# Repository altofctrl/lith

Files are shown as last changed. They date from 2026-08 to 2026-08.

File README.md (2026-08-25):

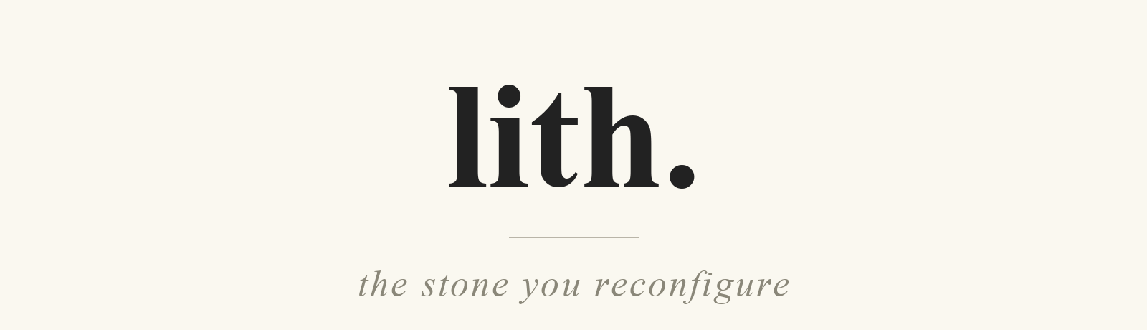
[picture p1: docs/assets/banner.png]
lith, the stone you reconfigure


<p align="center">
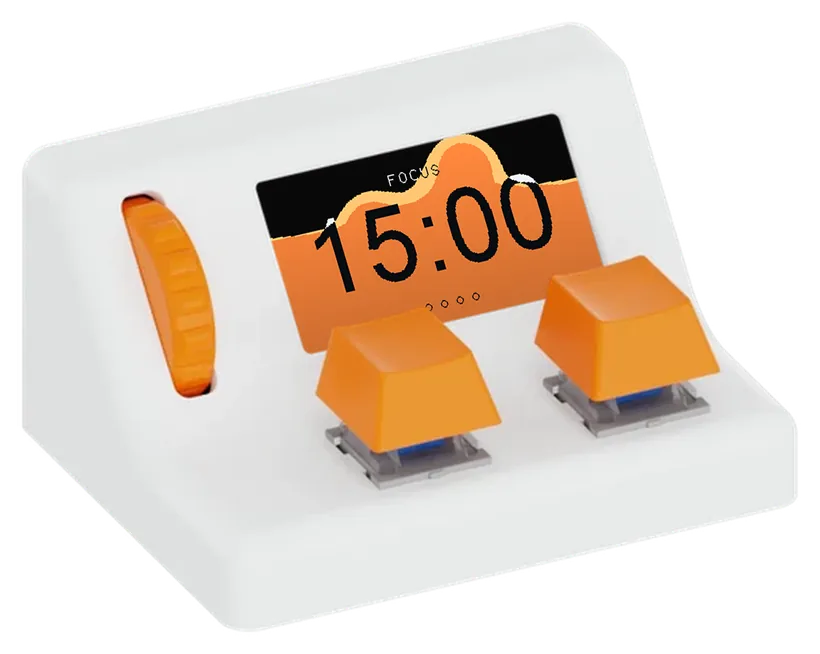
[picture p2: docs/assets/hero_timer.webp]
a lith running its pomodoro timer: a metaball fluid rising behind the countdown on the device's display
  
</p>

## the oldest tool we know how to make

1931, Olduvai Gorge, Tanzania.

In a ravein cut through the Serengeti plain, researchers discovered stones that had been deliberately broken, intentionally struck with larger ones till sharp flakes came away. They call this era of tool making **Oldowan** after the gorge, and it has examples dating back to 2.6 million years ago.

A stone chopper is the simplest
thing that is unmistakably *made*, and for most of the time there have been
hominins at all, it was the most complicated thing anyone could do. Making one
is harder than it looks: you have to read the stone, find a platform, and strike
at an angle that takes a flake off rather than shattering the core. People who
try it without being shown mostly fail.

These tools are some of the simplest things that can be unmistakably *made*, for most of the time we've been about it was the most complicated thing anyone could do.
However making one takes some skill, finding the right stone, striking the right angle with enough force to flake off instead of shatter.

_Knapping_ is difficult enough to learn, and
useless enough to invent from scratch, that it had to be **taught**. A 2015
experiment by Morgan and colleagues found that transmitting Oldowan technique
got measurably better as you moved from letting people watch, to gestural
teaching, to teaching with words.[1] Their argument is that toolmaking and
language leaned on each other as they grew. The first thing we made and the
first thing we said may have been the same conversation: *here, hold it like
this.*

## what lith is

lith is a small desk object: an ESP32-S3, a 320x170 display, a scroll wheel,
two key switches and a vibration motor in a printed shell. Out of the box it is
a pomodoro timer. That is the shape it arrives in, not the shape it has to keep.

The name is from *líthos*, stone. You reconfigure it by **knapping** it: you
describe what you want it to be, an agent called Oldowan writes the firmware,
and it is flashed to the device from the browser. The tools people make get
shared in the knappery.

The reason it is built this way is Bandura's: self-efficacy, the belief that
you can actually do the thing, is built most strongly from **mastery
experience**, and after that from watching someone like you succeed.[2] Which
role model, and for whom, turns out to matter: a systematic review by
Gladstone and Cimpian found that the effect depends on how *similar* the model
seems and how *attainable* their success looks, and that a model whose success
reads as out of reach can demotivate rather than encourage.[3] lith is
arranged so a beginner gets all three. You *watch* it be made through short form video content. You *make* one, by building it from its constituent parts. Then you *use* the
thing you made, on your desk, developing your own firmware by hand or with Oldowan's help.

[point on how overcoming the first hurdle towards that mastery experience improves continutity] 

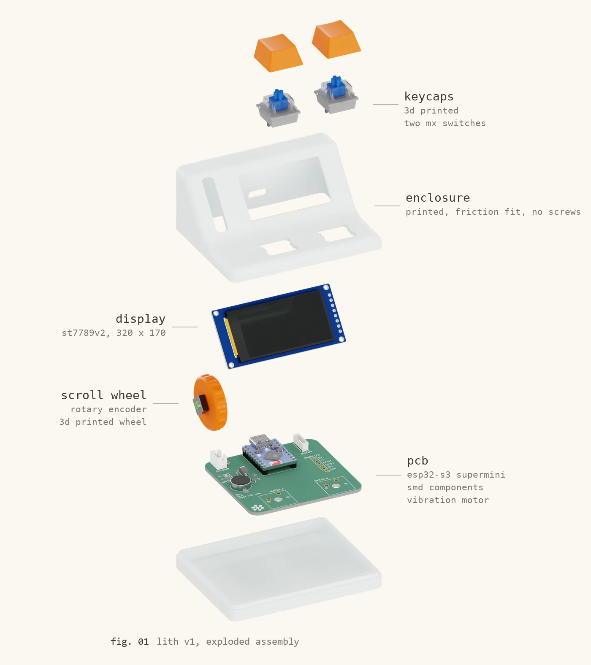
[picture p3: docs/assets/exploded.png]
lith v1, exploded assembly, with parts labelled


## what is in here

| | |
|---|---|
| [`firmware/`](firmware/) | The PlatformIO project that runs on the device. The pomodoro timer, the metaball fluid renderer, the display and input drivers. This is the stock shape lith ships in. |
| [`website/`](website/) | [lith.vidalion.co](https://lith.vidalion.co). The scroll-driven homepage, the onboarding walkthrough, the knapping bench and the knappery, every earlier version of them, and the Oldowan agent that writes firmware from a conversation. |
| [`research/`](research/) | Two studies run against the agent: whether the model tier behind Oldowan changes the quality of what it builds, and what the providers cost and how long they take. |

### website/

- `site/`: the four pages as they are served. `index.html` is the scroll-driven
  homepage, `onboarding.html` the walkthrough a new lith arrives with,
  `knapp.html` the knapping bench where you talk to Oldowan and flash the
  result from the browser, and `knappery.html` the shelf of builds other
  people have published.
- `agent/`: Oldowan. `oldowan.py` is the conversation and prompt layer,
  `builder.py` compiles and repairs the sketch it produces, `knappery.py` is the
  sharing side. `providers.json` selects the model; keys come from a
  `secrets.json` that is not in this repo.
- `versions/`: dated snapshots of every earlier version of the pages, back
  to before the renders existed.
- `assets/`: the WebP sequences the site actually serves.

### research/

- `ui-judge/`: 19 firmware builds from 11 models across 5 providers, compiled,
  rendered on the simulator and judged. The headline is that the **repair loop
  matters more than the model tier**: first-pass compile rate was 26%, and the
  builder's own repair passes took it to 79%.
- `provider-cost-latency/`: wall-clock latency and list price across the
  providers Oldowan can run on, replayed through one real 3-turn conversation.

Both are written up with their figures in
[`research/README.md`](research/README.md).

## references

1. Morgan, T. J. H., Uomini, N. T., Rendell, L. E., et al. (2015). Experimental
   evidence for the co-evolution of hominin tool-making teaching and language.
   *Nature Communications*, 6, 6029. https://doi.org/10.1038/ncomms7029

2. Bandura, A. (1997). *Self-Efficacy: The Exercise of Control*. W. H. Freeman.

3. Gladstone, J. R., & Cimpian, A. (2021). Which role models are effective for
   which students? A systematic review and four recommendations for maximizing
   the effectiveness of role models in STEM. *International Journal of STEM
   Education*, 8(1), 59. https://doi.org/10.1186/s40594-021-00315-x

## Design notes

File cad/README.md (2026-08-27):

# cad

Mechanical and PCB source for lith v1.

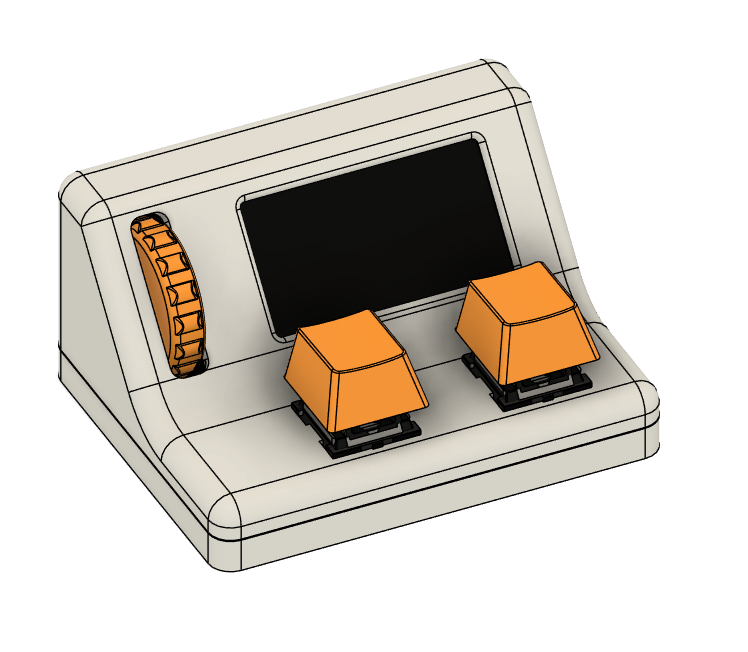
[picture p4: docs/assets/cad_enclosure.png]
lith v1 top shell: display cutout, two switches with keycaps, and the scroll wheel


    lith_assy_v1.step        full assembly, mechanical solids and PCB copper
    mechanical/
      lith_assy_v1.f3d       the Fusion source
      enclosure_top.stl      top shell, display cutout and switch plate
      enclosure_bottom.stl   base
      encoder_wheel.stl      scroll wheel
      keycap.stl             keycap, one per switch
    pcb/
      v1.0/                  KiCad project, first board
      v1.1/                  KiCad project, second board
        lith.kicad_sch       schematic
        lith.kicad_pcb       layout
        jlcpcb/gerber/       the fab output that was sent to JLC
        customs.pretty/      footprints drawn for this board

Each board folder is a self-contained KiCad project: it carries its own
`fp-lib-table` / `sym-lib-table` and the non-stock symbols, footprints and
connector 3D models the design pulls in, so it opens without the rest of the
library set.

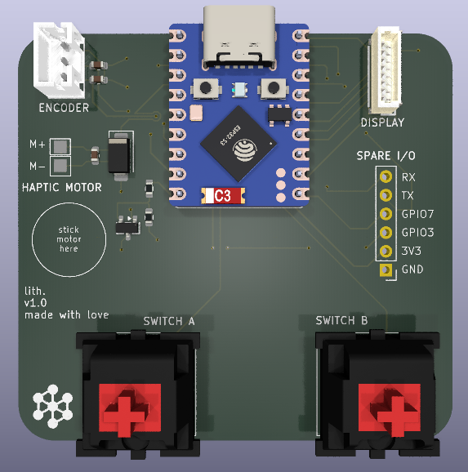
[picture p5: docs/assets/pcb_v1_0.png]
lith v1.0 board: the ESP32-S3-Zero module, encoder and display connectors, haptic motor pads, the spare I/O header and the two key switches


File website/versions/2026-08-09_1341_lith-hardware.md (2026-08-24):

# lith v1 · hardware reference

For anyone knapping their lith by hand in an IDE (Arduino IDE, PlatformIO, etc.)
instead of through Oldowan. This is the same ground truth Oldowan itself
builds from, paste it into your IDE's project notes, or straight into an AI
coding assistant if you're using one alongside your IDE.

## Board

- **ESP32-S3-Zero** (supermini form factor), 4MB flash QIO, native USB, CDC on boot
- Arduino core: `esp32` 3.x
- FQBN: `esp32:esp32:esp32s3:CDCOnBoot=cdc`
- Flash offsets: bootloader `0x0` · partitions `0x8000` · boot_app0 `0xe000` · app `0x10000`

## Pin map

| Signal | Pin |
|---|-----|
| TFT SCLK | 12  |
| TFT MOSI | 11  |
| TFT DC | 13  |
| TFT CS | 10  |
| TFT RST | 9 |
| TFT BLK | 8 |
| SW1 | 1 |
| SW2 | 2 |
| ENC_A | 4 |
| ENC_B | 5 |
| MOTOR | 6 |

## Display

ST7789V2, 170×320, driven with **LovyanGFX**. After `tft.setRotation(1)` it's
320×170 landscape. Reuse this init verbatim: the panel needs exact offsets
that aren't guessable from a datasheet:

```cpp
#define LGFX_USE_V1
#include <LovyanGFX.hpp>
class LGFX : public lgfx::LGFX_Device {
  lgfx::Panel_ST7789 _panel; lgfx::Bus_SPI _bus; lgfx::Light_PWM _light;
public:
  LGFX() {
    { auto cfg = _bus.config(); cfg.spi_host = SPI2_HOST; cfg.spi_mode = 0;
      cfg.freq_write = 50000000; cfg.freq_read = 16000000; cfg.spi_3wire = false;
      cfg.use_lock = true; cfg.dma_channel = SPI_DMA_CH_AUTO;
      cfg.pin_sclk = 12; cfg.pin_mosi = 11; cfg.pin_miso = -1; cfg.pin_dc = 13;
      _bus.config(cfg); _panel.setBus(&_bus); }
    { auto cfg = _panel.config(); cfg.pin_cs = 10; cfg.pin_rst = 9; cfg.pin_busy = -1;
      cfg.panel_width = 170; cfg.panel_height = 320; cfg.offset_x = 35; cfg.offset_y = 0;
      cfg.offset_rotation = 2; cfg.readable = false; cfg.invert = true;
      cfg.rgb_order = false; cfg.dlen_16bit = false; cfg.bus_shared = false;
      _panel.config(cfg); }
    { auto cfg = _light.config(); cfg.pin_bl = 8; cfg.invert = false;
      cfg.freq = 44100; cfg.pwm_channel = 7; _light.config(cfg); _panel.setLight(&_light); }
    setPanel(&_panel);
  }
};
// usage: LGFX tft; tft.init(); tft.setRotation(1); tft.setBrightness(180);
```

Draw into a 16-bit 320×170 `LGFX_Sprite` and `pushSprite()` it once per frame
rather than drawing primitives straight to the panel, avoids flicker/tearing.

## Switches

Two MX-style mechanical keyswitches, SW1 and SW2, wired **active low**. Use
`INPUT_PULLUP`. Debounce in software (~25 ms) and distinguish a short tap from
a long press (~800 ms hold); don't block waiting for either, compare against
`millis()` each loop pass.

## Encoder

The orange side scroll wheel: quadrature on ENC_A/ENC_B, `INPUT_PULLUP`, 4
quadrature steps per detent. **Keep this interrupt-driven, never polled in
`loop()`.** Attach a `CHANGE` interrupt on both pins into a small ISR that
only updates a `volatile` raw counter via a quadrature lookup table (no
Serial/heap/drawing inside the ISR). `loop()` reads that counter with
interrupts briefly disabled, divides by 4 to get detents, and only reacts to
the delta since the last detent; reacting per raw edge (4x too often, plus
contact bounce) makes scrolling feel jittery instead of matching the wheel's
physical click. This is also what decouples scroll responsiveness from
whatever else `loop()` is doing that tick (rendering, motor, etc.); the
single most common way a homebrew lith sketch ends up feeling laggy is
polling the encoder pins inside the render/update cadence instead of off an
interrupt.

## Vibration motor

Small motor behind an NPN low-side switch on the MOTOR pin. Drive with LEDC
PWM at 20 kHz, 8-bit resolution. Duty ~190 for a gentle buzz, 255 briefly for
a crisp tap. Treat it as fire-and-forget: set a `millis()`-based deadline and
let a small `motorService()` called every loop turn the PWM on/off
accordingly; never block waiting for a pulse to finish, and always let duty
fall back to 0 when idle.

## Libraries available on the build server

If you're compiling locally in an IDE you aren't limited to this list, but
anything you want to eventually publish through the knappery has to build on
these:

- LovyanGFX (display, reuse the init snippet above)
- QRCode by ricmoo (`qrcode.h`)
- Preferences (ESP32 NVS key-value storage)
- everything in the ESP32 Arduino core 3.x (WiFi, BLE, LEDC, etc.)

## Engineering heuristics

Distilled from the hardware bring-up sketch (`firmware/sketches/bringup.cpp`
in the [lith firmware repo](https://github.com/altofctrl/lith)). These are
what keep a lith sketch feeling responsive instead of laggy:

- Never call `delay()` in `loop()` or anywhere on the hot path. Every
  subsystem (buttons, motor, animation) should be driven off
  `millis()`-based timestamps so one slow feature can't stall input handling
  for the others.
- The encoder stays interrupt-driven, converted to detents before you act on
  it (see above); this is the single biggest lever on scroll feel.
- Debounce switches (~25 ms) and split short vs. long press (~800 ms)
  non-blocking.
- Throttle screen redraws to a fixed cadence (~25-40 fps) instead of drawing
  every loop iteration; draw into an off-screen sprite and push it once per
  frame.
- Motor/haptic output is fire-and-forget via a deadline timestamp, never a
  blocking wait.
- Drain all available Serial input each loop pass (`while (Serial.available())`),
  not one byte per pass.
- Use fixed-size `char` buffers with `snprintf` for logging/formatting, not
  the `String` class, to avoid heap fragmentation in a sketch that runs
  indefinitely.
- Keep `loop()` a short dispatch of small per-subsystem functions, each
  guarded by its own timing check, rather than inlining state machines
  directly in `loop()`.
- Net effect: any new feature must never come at the cost of encoder/button
  responsiveness. If something needs to block, block a state machine's
  transition, not the loop.
- There is no visible LED on the enclosure. Don't write status blinks,
  `digitalWrite` on the onboard LED pin, or any LED-based feedback into a
  sketch; the screen and motor are the only user-visible outputs.

## Stock firmware

The shipped firmware is a pomodoro timer: encoder sets the length shown when
idle; SW1 short press starts/pauses/resumes, SW1 long press resets the phase;
SW2 short press skips to the next phase, SW2 long press cycles which setting
the encoder edits; every fourth break is long. It also shows a QR splash to
`lith.vidalion.co/onboarding` for the first 10 boots after each new flash.
Full source: `firmware/src/main.cpp` in the
[lith firmware repo](https://github.com/altofctrl/lith).

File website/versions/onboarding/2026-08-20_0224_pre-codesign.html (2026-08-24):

← lith onboarding

onboarding

# 01 | welcomewell done.

Step one was "scan the code on the screen." Seeing as you're reading this, you did it.

This page is the manual. It's short, because the interesting part isn't what it does now. It's what you'll make it do later.

keystwo mx switches

enclosureprinted, pinch fit, no screws

displayst7789v2, 320 x 170

scroll wheelrotary encoder, orange

esp32-s3 superminithe brain, plus a haptic buzz

fig. 01 your lith, exploded · every part, in the order it goes together.

scroll ↓

## 02 | out of the boxit's a pomodoro timer.

Right now your lith runs its founding firmware: a focus timer built on the pomodoro method. Twenty-five minutes of work, five of rest.

- Turn the wheel to set the length, then tap the first key to start. Tap it again to pause, hold it to reset the phase.
  lith from the left. The wheel turns, the time climbs from 25 to 40 minutes, the first key goes down, and the screen fills as the timer starts
- The screen counts down. Nothing to press until it ends.
  lith head on. The number falls from 25:00 to 00:00 and the liquid on the screen drains with it
- When a block ends, lith buzzes and rolls into a 5 minute break. Tap the second key to skip ahead; hold it to choose which setting the wheel edits.
  lith with both keys facing you. The block runs out, the device buzzes, the screen turns green for a break; the second key is tapped and the break is skipped, then held down until the screen switches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
- Every fourth break is a long one.
  lith from a high angle. The fourth focus block runs out and the screen turns green for a long break, all four dots now filled

by the way: the QR splash you scanned retires itself after the first ten boots.

## 03 | one stone, many toolsthe timer is just the first shape.

lith is a reconfigurable computer. The pomodoro firmware is one arrangement of it, the way a hand axe is one use of a flint. You can reshape yours: a macropad, a bus countdown, a word of the day display or knap it right back to the default pomodoro whenever you want.

knap /nap/ · verb · to shape a stone tool by striking flakes from it. Here: to shape your lith into a new tool by describing the tool you want.

## 04 | knapp your owntwo ways to shape it.

However you'd rather work: talk to an agent, or open an IDE and wire it up yourself. Both start from the same hardware.

agent

### chat with oldowan

Oldowan is the agent you knapp with, named after the oldest known stone toolkit. Tell it what you want your lith to become, answer a few multiple-choice questions, and it writes the firmware and walks you through flashing it. No code required, though you can read every line it writes.

open the knapping bench →

or

diy

### wire it up yourself

Prefer Arduino IDE (https://www.arduino.cc/en/software), PlatformIO (https://marketplace.visualstudio.com/items?itemName=platformio.platformio-ide), or your own coding agent at the wheel? Here's the hardware ground truth: pin map, display init snippet, and the timing rules that keep the encoder feeling immediate instead of laggy.

- pin map + display init
- libraries the build server has
- engineering heuristics from bring-up

download hardware.md →

you

I want my lith to remind me to water the plants.

oldowan

Good use of a stone. How should it remind you?

a a plant sprite that wilts on screen until you press the button

b a gentle chime every morning at a set time

c only when the soil sensor I'll wire up says so

… or type your own answer

you'll need a laptop for the flashing part. Knapping flashes new firmware onto your lith over USB, straight from the browser using Web Serial. That works in Chrome or Edge on a laptop or desktop. It does not work from phones, and not in Firefox or Safari, which don't support Web Serial. You can start chatting and shaping from the phone you're holding, then open the same link on a laptop to flash; your conversation travels with it.

## 05 | the knapperytools are for sharing.

Every knapp can be published to the community, where anybody can flash it, star it, and discuss it under the listing, like a forum stitched to a toolbank. Always read the source before you flash something a stranger knapped. A report button is on every listing, and a small model skims each published sketch and quietly flags anything that looks off for a human to check. Treat that as a backstop, not a guarantee: nothing is blocked automatically, and it is no substitute for reading the code yourself.

open the knappery →

## 06 | that's itgo focus.

Press the button on your lith and get 25 minutes of something done. If you wish it did something else, knapp it.

back to lith.vidalion.co →

lith.vidalion.co/onboarding · a vidalion (https://vidalion.co) joint · mmxxvi

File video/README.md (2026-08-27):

# Mastery Modeling

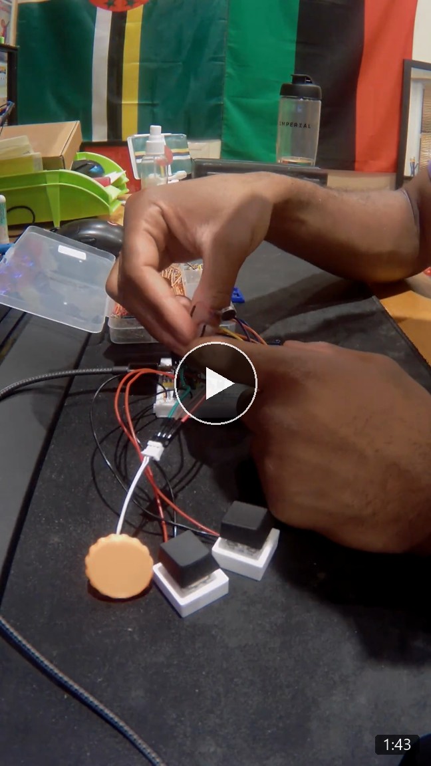
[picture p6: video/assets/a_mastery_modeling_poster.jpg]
Mastery Modeling
[](a_mastery_modeling.mp4)

# Coping Modeling

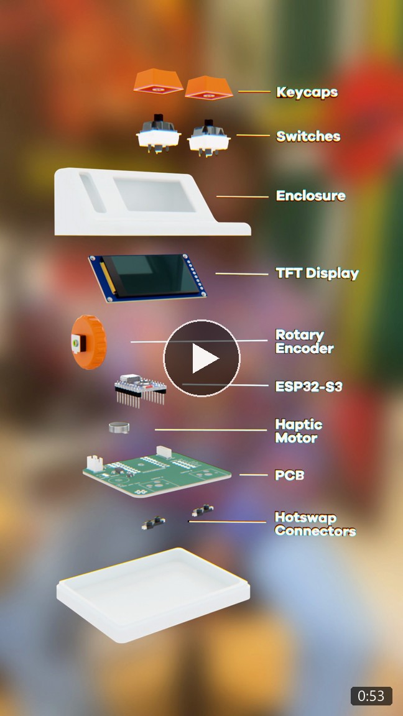
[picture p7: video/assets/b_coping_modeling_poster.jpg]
Coping Modeling
[](b_coping_modeling.mp4)

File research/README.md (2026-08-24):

# research

Two studies, both aimed at the same question from different sides: **can a
language model be trusted to write the firmware a beginner asked for?** One
looks at the quality of what comes out, the other at what it costs to get it.

Both run against Oldowan, the co-design agent in [`../website/agent/`](../website/agent/).

---

## ui-judge

19 firmware builds, generated from one brief by 11 models across 5 providers,
compiled, rendered on a simulator that runs the sketches as the device would,
and then judged.

### the repair loop matters more than the model

This is the finding that changed how the agent is built. Straight out of the
model, only 5 of 19 builds compiled. After `builder.py`'s repair passes, 15 of
19 did.

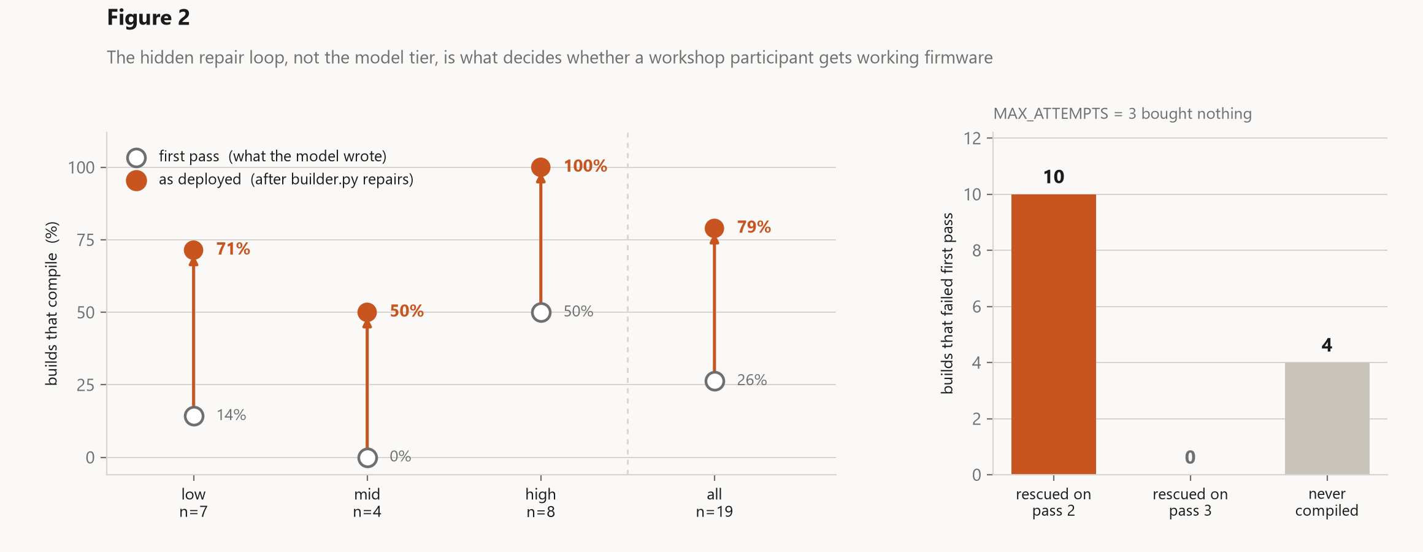
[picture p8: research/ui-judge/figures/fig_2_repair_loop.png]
First-pass versus as-deployed compile rate, and which pass rescued each build


Every rescued build was fixed on **pass 2**. `MAX_ATTEMPTS = 3` bought nothing
on this brief, which means the third attempt is cost with no return.

### tier buys hierarchy, not coverage

Every build that compiles distinguishes more or less all six states of the
journey, so journey coverage does not separate the tiers at all (p = 0.87).
What separates them is whether the screen is laid out well.

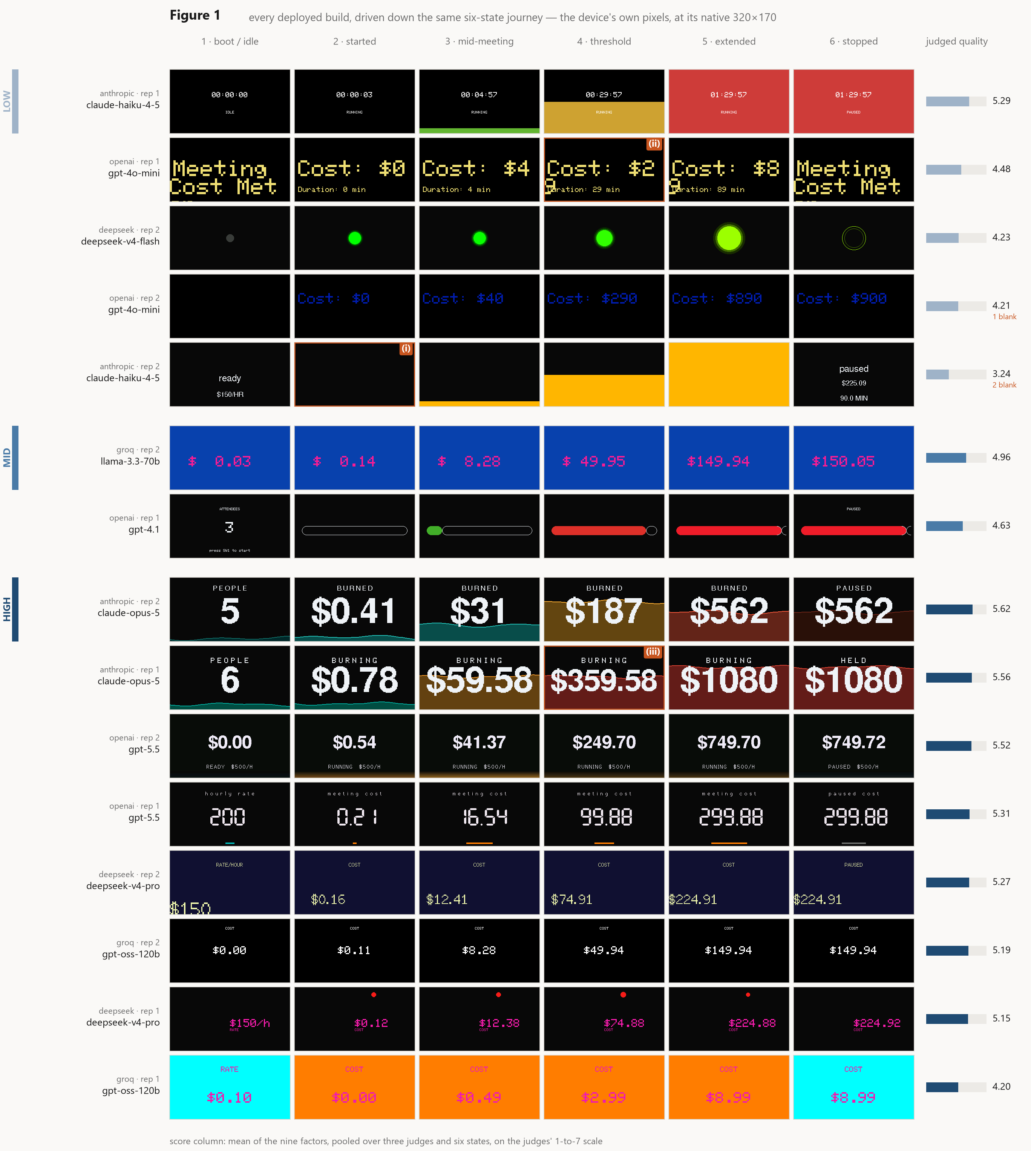
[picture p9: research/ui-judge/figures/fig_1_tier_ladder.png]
15 builds by 6 journey states, sorted by judged quality within tier


That matrix is 2735 x 3052 px, which is right for reading on screen and useless
once a word processor scales it into a column. The same journey, one
representative build per tier, sized for a 16 cm text column:

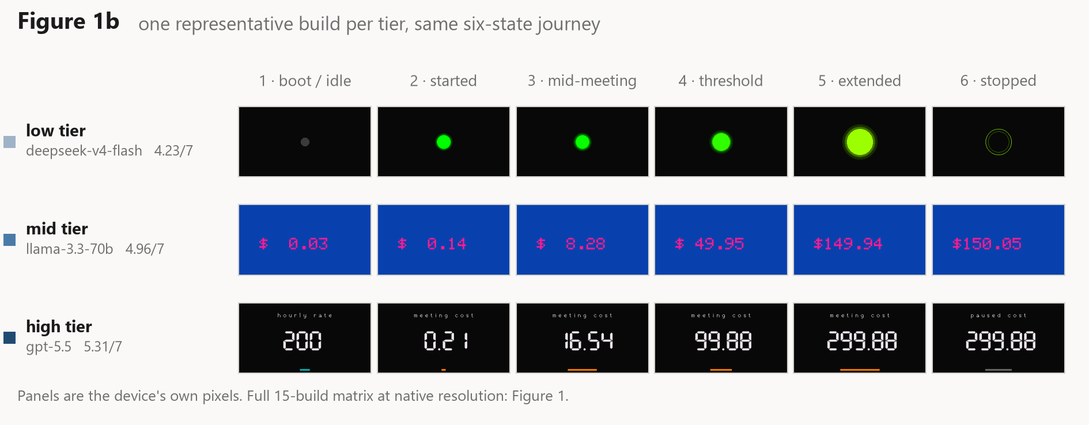
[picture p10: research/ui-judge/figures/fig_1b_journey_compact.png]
One representative build per tier across the six-state journey


The three rows are the argument in miniature. All three compile, all three
cover the journey, and all three are honestly reporting the same running cost.
The low-tier build says it with a green dot that gets bigger. The mid-tier
build says it with a bare number. Only the high-tier build tells you what the
number *is*, puts the label above it, and gives the state its own indicator.

On the pairwise task the higher tier wins 0.90 of the time. But rep-to-rep
variance beats the tier effect: two `claude-haiku-4-5` runs of the same prompt
differ by 2.05 on the nine-factor mean, where the whole low-to-high tier gap is
0.94.

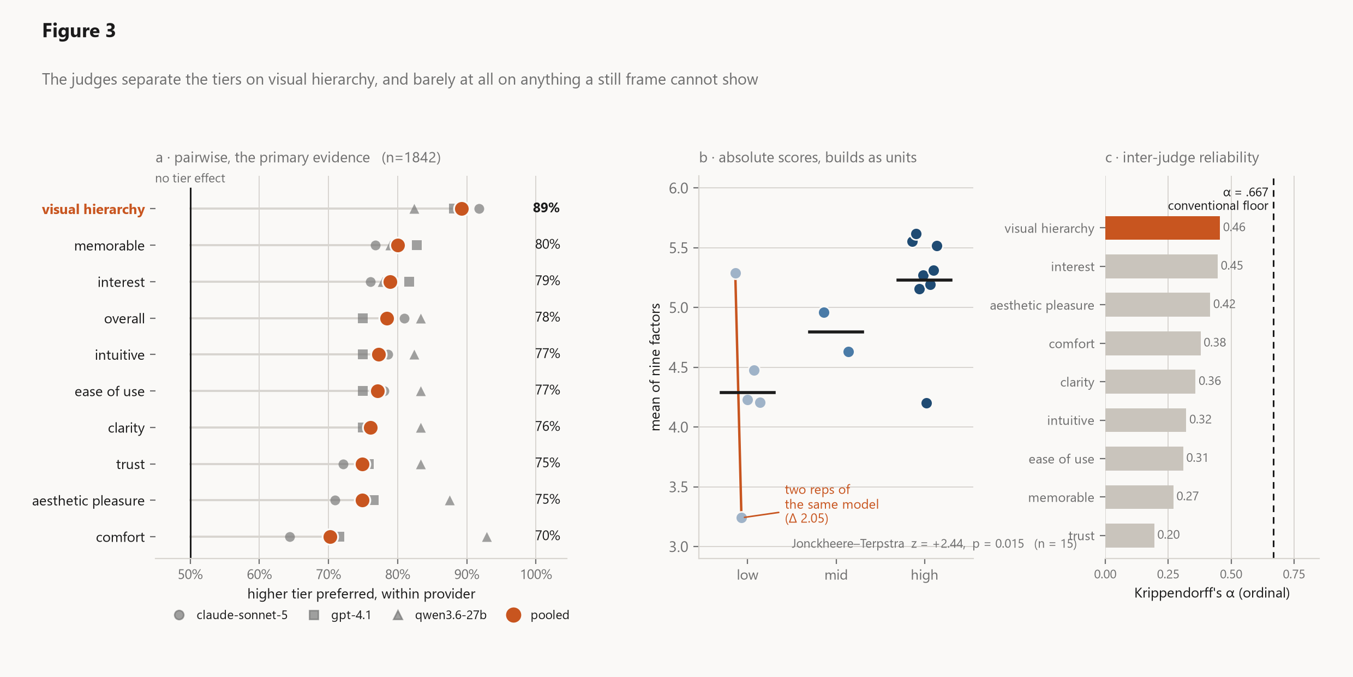
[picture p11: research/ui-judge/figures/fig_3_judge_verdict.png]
Pairwise win rate by factor, per-build scores by tier, and inter-judge agreement


Inter-judge agreement is weak (Krippendorff's alpha 0.35), so the absolute
Likert scores are descriptive only. The pairwise comparison is what carries the
argument.

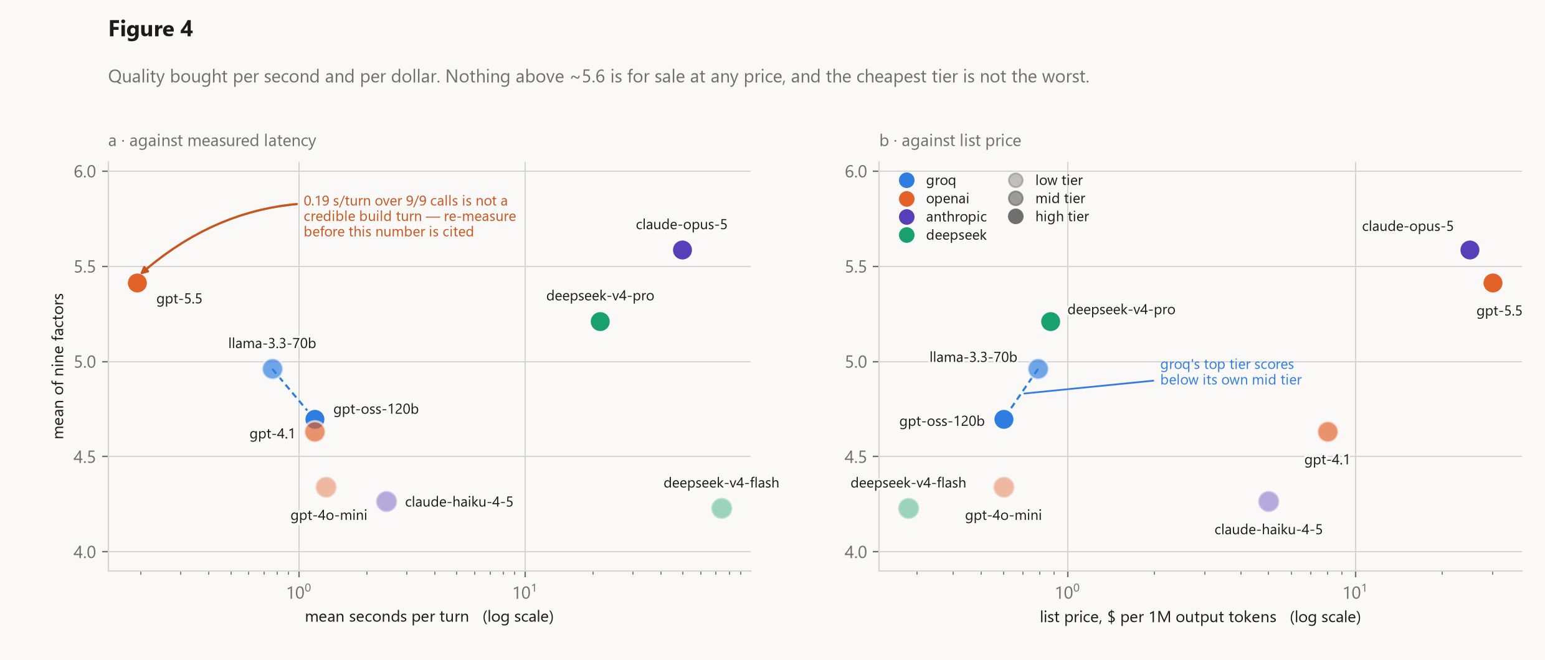
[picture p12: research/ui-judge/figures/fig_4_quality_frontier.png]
Nine-factor mean against measured latency and against list price


### where the instrument comes from

The nine factors are not invented here. They are taken from Luera et al.,
*MLLM as a UI Judge* (arXiv:2510.08783), an Adobe Research benchmark that
validates multimodal LLMs as predictors of human perception of interfaces:
ease of use, clarity, visual hierarchy, memorability, trust, intuitiveness,
aesthetic pleasure, interest and comfort, checked against 9,296 human Likert
responses over thirty interfaces with GPT-4o, Claude 3.5 Sonnet and
Llama-3.2-11B-Vision as the judges. Their Table 1 gives the battery, their
Figure 7 gives the prompt, and their Task 2 is the pairwise comparison used
here.

Their results are the reason this study is shaped the way it is. Their judges
land within one Likert point of the human mean 72 to 77% of the time, but get
the *exact* score right only 35 to 38% of the time. So absolute scores are
soft and comparisons are firm, and the design follows: score everything, but
argue from the pairwise task.

That paper is itself the UI-specific descendant of a now-standard method.
LLM-as-a-judge was established by Zheng et al., *Judging LLM-as-a-Judge with
MT-Bench and Chatbot Arena* (NeurIPS 2023 Datasets and Benchmarks,
arXiv:2306.05685), which showed a strong model scoring open-ended text could
reach roughly the 80% agreement with human preference that humans reach with
each other, and which named the failure modes that come with it: position
bias, verbosity bias, and self-enhancement bias, the tendency of a judge to
prefer its own output.

Those three biases are why this run is built the way it is. Every pairwise
comparison is shown in **both A/B orderings**, so a judge that flips when the
options are swapped is recorded as having no preference rather than being
silently resolved in whichever direction it happened to be asked. The judges
are drawn from **three different model families** (`claude-sonnet-5`,
`gpt-4.1`, `qwen3.6-27b`) precisely so that self-enhancement cannot quietly
decide the ranking, since a judge scoring builds from its own family is the
obvious hazard when the thing being judged is model output. And each frame is
scored three times with the median taken, to damp sampling noise.

**One honest correction to how this study describes its own source.** The
protocol justified treating pairwise as primary by citing Luera et al.'s
"roughly 90%" pairwise agreement. That figure applies only to the subset of
comparisons where two interfaces were separated by a large human score gap.
Their *overall* pairwise accuracy against human preference is 52.96 to 59.98%
(Claude 59.98%, GPT-4o 59.60%). The design choice still stands, and this run's
own alpha of 0.35 independently says the absolute scores cannot carry the
argument. But the pairwise result here should be read against a 53 to 60%
baseline, not against 90%.

**The chain of borrowed validation gets thinner at every link.** Zheng et al.
validated judges on text. Luera et al. carried the method across the modality
gap to rendered, full-size, professionally designed web screens. This study
carries it one gap further, onto a 320x170 embedded panel showing six frames
of a timer. No human ratings of *these* screens were collected. What is
established here is how MLLM judges rank the output of different provider
tiers. That lith's actual users would rank them the same way is assumed, not
shown.

### where to look

| | |
|---|---|
| [`RESULTS.md`](ui-judge/RESULTS.md) | The full write-up of the run. |
| [`SECTION_codesign_agent.md`](ui-judge/SECTION_codesign_agent.md) | The ~1,800-word report section this became. |
| [`DEVIATIONS.md`](ui-judge/DEVIATIONS.md) | Where the run departed from the written protocol. |
| [`results/`](ui-judge/results/) | Every CSV and raw judge response. |
| [`code/`, `code_deployed/`](ui-judge/code/) | The sketches as generated, and as they ended up after repair. |
| [`harness/`](ui-judge/harness/) | The gates, the judges, the simulator and `make_figures.py`. |

Run 2026-08-16; written up 2026-08-20.

---

## provider-cost-latency

Wall-clock latency and list price across every provider Oldowan can be pointed
at, replayed through one real 3-turn conversation taken verbatim from a session
rather than a synthetic prompt.

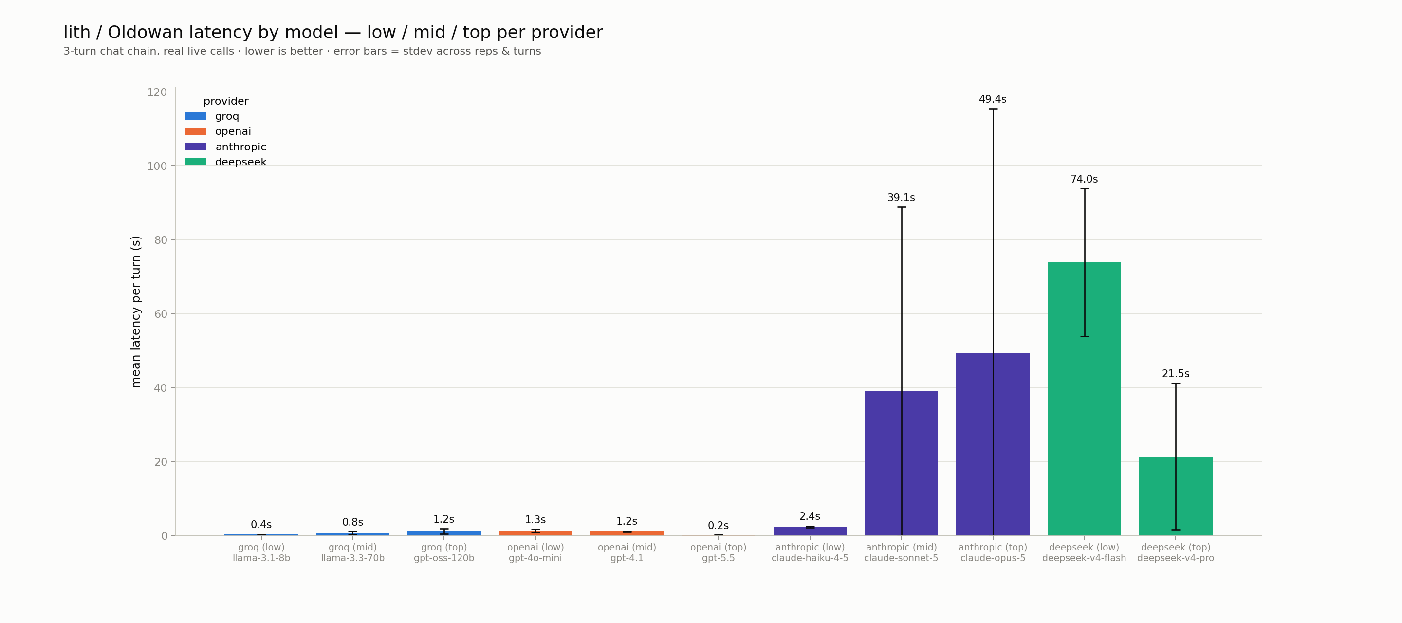
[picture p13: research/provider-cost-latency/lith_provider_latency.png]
Mean latency per turn by model, grouped by provider


Groq is the latency floor by a wide margin, which is the inference hardware
rather than a small-model effect. The reasoning-heavier models are both slower
and far noisier, and for an agent that streams its answer to someone waiting,
the spread matters as much as the mean.

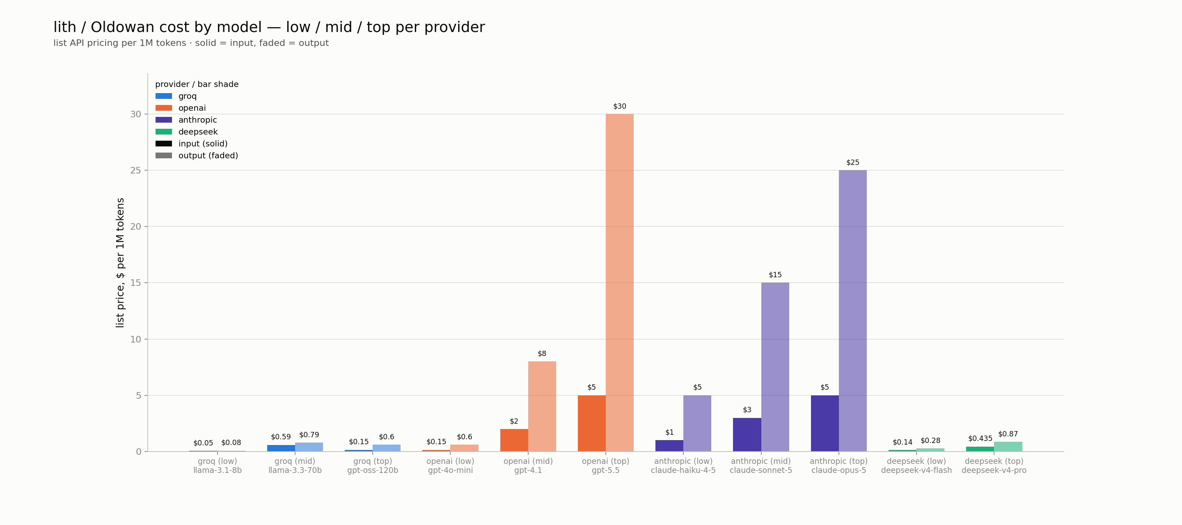
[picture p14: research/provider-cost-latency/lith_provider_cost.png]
Input and output list price across the 11-model matrix


Run 2026-08-10.

### read the spreadsheet, not the prose

Three things anyone using this data needs to know first:

- **`lith_provider_latency.md` is stale against `lith_provider_latency.xlsx`.**
  The prose describes an 8-model run; the sheet, saved 37 minutes later, is an
  11-model run that disagrees hard (sonnet-5 at 39.087 s mean, not 1.78 s
  stdev). Trust the sheet.
- `bench_build.py` and `bench_latency.py` hand `oldowan._call_anthropic`'s
  return value straight to `parse_envelope`, but the anthropic path returns a
  dict where the openai path returns a bare string. The anthropic rows in the
  older CSVs are wrong because of it.
- The `gpt-5.5` figure (0.193 s mean, 0.012 s stdev) is not plausible and needs
  re-measuring before it is cited anywhere.

One more trap for anyone re-running a tier sweep: `providers.json` sets
`effort: medium`, and `claude-haiku-4-5` returns a 400 on that field. It has to
be dropped for that model specifically.

---

## what this suggests for lith

Six things follow from the two studies. They are ordered by how much they
would change if acted on.

**1. Spend on the repair loop, not on the model.** This is the largest
effect in either study by a wide margin: 26% of builds compiled on the first
pass, 79% after repair. No tier upgrade available anywhere in the price table
buys a jump of that size. If there is engineering time to spend on the agent,
it goes into `builder.py`, not into `providers.json`.

**2. Set `MAX_ATTEMPTS = 2`.** Every build that repair rescued was fixed on
pass 2. The third attempt rescued nothing on this brief while costing a full
generation round-trip on the slowest path a user can be on. Keep the third
pass only if a later brief shows it earning its place.

**3. Sample rather than upgrade.** Two runs of the same prompt on
`claude-haiku-4-5` differ by 2.05 on the nine-factor mean; the entire
low-to-high tier gap is 0.94. Variance is more than twice the signal. That
makes best-of-k on a cheap fast model a better use of the same money than one
attempt on an expensive one, and the pairwise judge is already the instrument
for picking the winner.

**4. Put hierarchy in the prompt, since that is what tier is actually
buying.** Journey coverage does not separate tiers at all (p = 0.87).
Everything that compiles shows all six states. What separates them is visual
hierarchy, and Figure 1b shows what that means concretely: one dominant
value, a label that says what the value is, and a state indicator that is not
the value itself. Those are writable rules. Encoding them in
`device_profile.json` would hand the low tier most of what the high tier is
being paid for.

**5. Treat latency as a design property, not an implementation detail.**
Groq returns in well under half a second; `claude-sonnet-5` averages 39
seconds with a 49-second standard deviation. Somebody knapping their first
lith is watching a spinner for that whole time, on the exact afternoon the
project is trying to convert into a mastery experience. A fast model for the
first build with a strong model held back for refinement fits both the
self-efficacy argument and the cost table.

**6. Buy the human validation before the claim is load-bearing.** The
instrument's alignment with human judgement is inherited from a paper about
full-size web screens. Thirty people rating a subset of these frames would
convert the weakest part of the argument into the strongest, and it is a
morning's work. Until then, phrase findings as "MLLM judges prefer" rather
than "users prefer".

One caution that cuts against acting too hard on any of this: all 19 builds
answer a single brief, the mid tier is unbalanced and missing
`claude-sonnet-5` entirely, and six still frames discard motion, which is a
large part of what a glanceable display actually does. The repair-loop finding
is robust because it is enormous. The tier findings are directional.

---

## references

1. Luera, R., et al. (2025). MLLM as a UI Judge: Benchmarking Multimodal LLMs
   for Predicting Human Perception of User Interfaces. arXiv:2510.08783.
   https://arxiv.org/abs/2510.08783

2. Zheng, L., Chiang, W.-L., Sheng, Y., et al. (2023). Judging LLM-as-a-Judge
   with MT-Bench and Chatbot Arena. *Advances in Neural Information Processing
   Systems 36, Datasets and Benchmarks Track*. arXiv:2306.05685.
   https://arxiv.org/abs/2306.05685

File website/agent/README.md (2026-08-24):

# lith knapp backend

Oldowan chat + firmware compile + flash artifacts for lith.vidalion.co/knapp.
Flask on 127.0.0.1:3130, proxied by nginx at `lith.vidalion.co/api/`.

## Run

- Autostarts on boot via `@reboot` cron in aaron's crontab, in a screen
  session named `lith-knapp` (same pattern as backstage).
- Manually: `screen -dmS lith-knapp /home/aaron/lith-backend/run.sh`
- Health: `curl http://127.0.0.1:3130/api/health`

## Pieces

- `app.py`: Flask API (session, chat, build status, binaries, replay).
- `oldowan.py`: agent orchestration. JSON envelope protocol
  (say / ask / build / done), provider adapters, mock provider.
- `knappery.py`: community listings (SQLite `knappery.db`). No accounts;
  edit_token gates delete, voter_id dedups stars. Moderation is by hand via
  `admin.py`; nothing is hidden automatically.
- `builder.py`: single-worker compile queue using arduino-cli
  (`~/.local/bin/arduino-cli`, esp32 core 3.3.11, FQBN in
  `device_profile.json`). Hidden repair loop: compile errors go back to
  the agent as `[internal]` messages, up to 3 passes, invisible to the user.
- `providers.json`: the provider framework. `active` selects one. Formats:
  `anthropic` | `openai` (covers Groq/Mistral/DeepSeek/Ollama/vLLM/...) |
  `mock` (scripted, no key, for testing the full flow).
- `secrets.json` (not committed anywhere): `{"ANTHROPIC_API_KEY": "..."}`,
  referenced from providers.json as `${VARS}`. Env vars also work.
- `device_profile.json`: hardware ground truth injected into the system
  prompt; pin map is TODO until confirmed. Also carries FQBN and flash
  offsets for the esp-web-tools manifest.
- `sessions/`, `builds/`: runtime state, one JSON per session, one dir per
  build (sketch, out/ binaries, manifest.json, meta.json).

## Going live with a real provider

1. Put a key in `secrets.json` (chmod 600).
2. Set `"active"` in providers.json to `anthropic` (or another entry).
3. Restart: `screen -S lith-knapp -X quit; screen -dmS lith-knapp ./run.sh`

## Automated review (advisory)

Two small-model checks run on the provider's `guard_model`, both forced
single tool calls returning a JSON bool, and both fail open so a flaky API
call never blocks a user:

- `oldowan.is_adversarial()` screens chat input for jailbreak attempts
  before it reaches Oldowan's system prompt. Hits go to
  `adversarial_log.txt`. Two rules keep a false positive cheap: messages
  matching an option Oldowan just offered skip the guard entirely (that
  text is Oldowan's own, so there is nothing to classify), and a rejected
  turn is not written to the transcript, it just asks the user to rephrase
  and re-offers the question. Both exist because on 2026-08-13 the guard
  flagged one of Oldowan's own suggested options and silently killed a
  live session.
- `oldowan.review_knapp()` reviews each sketch published to the knappery.
  It runs off the request path in a daemon thread (`app._review_async`), so
  the listing goes live immediately either way. A concerning verdict files
  a normal row in the `reports` table prefixed `[auto] `, surfacing it in
  `./venv/bin/python admin.py reports` next to human flags. It never hides
  a listing or rejects a publish; a human still decides.

## Timeouts (the "oldowan is unreachable" failure)

Sketch generation is one non-streamed call with a big `max_tokens`.
Measured on claude-sonnet-5 (`bench_latency.py`): conversational turns run
9 to 21s, but the turn that writes the sketch took **137.9s**, and has been
seen over 180s. The original 150s `request_timeout_s` left ~12s of headroom,
so build turns timed out and the user got "oldowan is unreachable right
now" (a 502 from `/api/chat`) after waiting two and a half minutes.

Three values have to stay ordered, smallest to largest:

    guard_timeout_s (20s)  <  request_timeout_s (300s)  <  nginx proxy_read_timeout (330s)

If nginx is the smallest of the two large ones it 504s first and the user
sees a raw gateway error instead of Oldowan's own message. `nginx-api.snippet`
carries the matching value but the live config is root-owned, so changing it
needs sudo and a reload.

## Limits

Per-IP: 30 chat calls and 8 builds per hour (in-memory, resets on
restart). Sketch size capped at 200 KB. Compile timeout 7 min.

## Nginx

`nginx-api.snippet` in this directory must be included inside the
lith.vidalion.co server block (root-owned config, needs sudo).

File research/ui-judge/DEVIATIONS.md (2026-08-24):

# Deviations from the protocol as written

Every point where this run departs from `oldowan-ui-judge-microstudy.md`, with
the reason. Listed here rather than buried in the results so that anything read
off the numbers can be discounted appropriately.

## Design and corpus

**Two reps per model, not three.** The protocol specifies 3 generation reps per
model for 36 builds. This run reuses the corpus already generated for the
provider benchmark (`bench_all/code`), which has 2 reps, giving 19 builds across
11 models. Regenerating a third rep is 11 models x ~5 turns of live API calls
and was not affordable inside the session's time budget. The consequence is that
"small n" in X.6 is smaller still: 2 reps is enough to see a tier-scale
difference and not enough to say anything about a single model.

**The matrix resolved differently from the table in X.2.** X.2 names
`gpt-4o-mini` / `gpt-4.1-mini` / `gpt-4.1` for openai and "largest available"
for the other high tiers. The corpus was generated against what the providers
were actually serving, and the resolved matrix is:

| Provider | Low | Mid | High |
|---|---|---|---|
| Provider | Low | Mid | High |
|---|---|---|---|
| anthropic | `claude-haiku-4-5-20251001` ×2 | *(no builds)* | `claude-opus-5` ×2 |
| openai | `gpt-4o-mini` ×2 | `gpt-4.1` ×2 | `gpt-5.5` ×2 |
| groq | `llama-3.1-8b-instant` ×2 | `llama-3.3-70b-versatile` ×2 | `openai/gpt-oss-120b` ×2 |
| deepseek | `deepseek-v4-flash` ×1 | *(none served)* | `deepseek-v4-pro` ×2 |

Two gaps, both in the mid tier. deepseek has no mid model at all:
`deepseek-chat` and `deepseek-reasoner` resolve into the same v4 family, so the
provider offers two tiers, not three. And the inherited corpus contains **no
`claude-sonnet-5` sketches**, so anthropic's mid tier is missing entirely —
which is the one gap that could have been closed by regenerating, and was not,
for the time reason above. `deepseek-v4-flash` has one rep rather than two.

The matrix is therefore **10 model-tiers, not 12**, and badly unbalanced across
tiers: 7 low builds, 4 mid, 8 high, of which 5 / 2 / 8 survive to be judged.
The mid tier is the one to distrust. X.2's own note that "aliases drift" is why
the table and the run disagree on names; the resolved names are what the
analysis uses.

**One provider-block parameter had to be dropped per model.** `providers.json`
carries one config block per provider, tuned for the model that block normally
runs; the anthropic block sets `effort: medium`, which `claude-sonnet-5`
supports and `claude-haiku-4-5` rejects outright with a 400. A tier sweep across
one provider therefore cannot hold *all* sampling parameters at production
defaults the way X.2 asks. `effort` is dropped for the haiku tier only and left
in place everywhere it is accepted.

## Gate 1

**Gate 1 is reported twice.** The protocol measures compile success on the
model's first sketch. That is not what a workshop participant experiences:
`builder.py` never shows a compile error to the user, it returns the errors to
Oldowan as a hidden `[internal]` message and recompiles, up to `MAX_ATTEMPTS = 3`
passes. Since X.2 states the object of study is "`oldowan` as deployed", this
run reports both **first-pass** compile (the protocol's measure) and
**as-deployed** compile (after the production repair loop). The as-deployed
corpus is what Gates 2-3 render and what the judges score, because it is the
firmware a user would actually be holding.

**The repair loop runs on a reconstructed history.** Production carries the
model's own intermediate `ask` turns into the repair. The bench corpus kept only
the final sketch, so the reconstructed history is the three real user turns plus
the model's own build envelope, then the verbatim `[internal]` repair prompt
from `builder.py`. The repair reasons over the errors and its own code, which is
the load-bearing part, but it does not see the questions it asked on the way
there.

**The earlier `bench_build.py` CSVs are not used.** They are internally
inconsistent with the `.ino` files sitting beside them (rows reporting no build
for models that have sketch files on disk), having been written across several
partial runs with different nudge settings, and `bench_build.py` mishandles the
anthropic reply shape: `oldowan._call_anthropic` returns
`{text, stop_reason, usage}` while the openai-compatible path returns a bare
string, and the bench passes the dict straight to `parse_envelope`. Gate 1 here
is re-run from scratch over the corpus so it is one consistent table.

## Gate 2 (render)

**A native SDL-shim build, not Wokwi.** X.3 allows either. The harness
(`harness/sim/`) compiles each sketch against the real LovyanGFX with a
RAM-backed `Panel_FrameBufferBase` in place of the ST7789-on-SPI, so the pixels
come from the library the device runs: same glyph rasteriser, same RGB565
quantisation, same rotation maths, reading the sketch's own `offset_rotation`
out of its own panel config. Only the bus and the backlight are inert, because
neither appears in a frame.

**`Panel_Device::init` is skipped.** It drives the reset line, the backlight and
then `_bus->init()`; with no bus that last call is a dereference of null. What
it would otherwise do is hardware bring-up with no bearing on a pixel.

**Prototypes are generated, as arduino-cli does, but placed differently.** A
`.ino` is not a translation unit; the Arduino builder generates a forward
prototype for every sketch function before compiling. The harness does the same,
or sketches would fail here for a reason that has nothing to do with the model.
It places the block after the last top-level type declaration rather than at the
top of the file. arduino-cli's top-of-file placement is what produces the
`'Button' was not declared in this scope` failures visible in Gate 1 — the
prototypes land above the structs they mention. Gate 1 has already measured
that; Gate 2 asks what the UI looks like, and reproducing the placement bug here
would only stop screens from being seen.

**`-fpermissive`.** These sketches target the Arduino toolchain and a few lean
on its laxer conversions. Gate 1 is where strictness is the question.

## Gate 3 (journey)

**Time is stepped, not simulated continuously.** `millis()` is virtual and the
harness advances it in 1000 ms steps between capture points, tightening to 100
ms and then 20 ms in the last half-second before each capture. One second is the
coarsest safe stride: a meter that accrues on a `now - last >= 1000` tick
advances once per loop, so a longer step would under-count the money on screen —
the number being judged. A build that counts iterations rather than reading the
clock is still mis-driven by this, and the device profile does tell models to
use `millis()`.

**One scripted input sequence for every build.** SW1 is tapped to start and
tapped again to stop. Builds that chose SW2, or a hold, or an encoder turn as
their start control are not accommodated — by design, per X.3: the journey comes
from the brief, not from each build's own idea of its controls. A build whose
frames never change is recorded as covering one state, and that is a finding
about the build meeting the brief, not a harness failure. `rotation_set` and
`init_called` are recorded separately so a build that never rotated the panel is
visible as such rather than silently corrected.

**Absence is measured as frame-identity, not as a claim about intent.** Coverage
counts *distinct* frames among the six. Two journey states that render
identically are counted once.

## X.4 (judging)

**Three reps per judge, not ten.** The protocol takes the median of 10
repetitions per judge per frame to suppress sampling noise. This run uses 3.
Ten would have been ~3x the calls for a median that moves little; the cost is a
noisier median, which matters most where judges are near-indifferent.

**The third judge is Qwen, not Llama.** X.4 requires three MLLMs from different
families. Groq no longer hosts a Llama vision model, so the open-weight slot is
`qwen/qwen3.6-27b`. The other two are `claude-sonnet-5` and `gpt-4.1`. Three
distinct families is the property the protocol asks for, and it holds.

**Judge thinking is set to low effort.** `claude-sonnet-5` has extended thinking
on by default. Luera et al.'s judges answer directly, and a reasoning trace is
not part of the instrument.

**The prompts are the paper's, with one substitution and one added format
line.** The nine Table 1 factors, the 7-point scale, the Figure 7 wording and
the Task 2 criterion/result/reason structure are as published. The framing moves
from "an average user brought in to do human testing" to a user encountering a
small embedded device display, which X.4 specifies. A single sentence pinning
the response layout is appended so three model families can be parsed the same
way; it adds no content to the instrument.

**The open-weight judge's data is thinner than the other two.**
`claude-sonnet-5` and `gpt-4.1` returned a complete nine-factor score on all 90
frames. `qwen3.6-27b` did so on 72 of 90, and 45 of those rest on a median over
one rep rather than three: it reasons in a `<think>` block that cannot be turned
off and that often consumed the whole token budget before it answered, even at a
6,000-token ceiling. The first attempt at its pass also lost 211 of 270 calls to
groq rate limits before backoff was added. This is reported rather than
smoothed, because a missing score and a low score are not the same thing.

**Two parsing faults were found and fixed mid-run, and the affected judge was
re-run.** `gpt-4.1` answers the pairwise task with the criterion as the tag name
(`<ease of use>[UI-A]</ease of use><result>UI-A</result>`) rather than inside a
`<criterion>` element, which a `<criterion>`-anchored pattern misses entirely;
that silently dropped 18% of its comparisons on the first pass. The parser now
anchors on `<result>` and attributes each to the criterion named last before it,
and `gpt-4.1`'s whole pairwise task was re-run, recovering 1320/1320. The
pairwise raw log now also keeps the reply text, which it did not on the first
pass — without it a parse failure cannot be told from a judge that declined to
answer.

**Pairwise runs both orderings.** Not in the protocol, added here. An MLLM shown
two images has a position bias, and without the swap a bias toward the first
slot is indistinguishable from a real preference — it would surface as a tier
effect that is really an artefact of listing order. Each pair is judged twice
with the builds swapped; only agreement across both orders counts as a
preference, and a flip is recorded as a tie rather than resolved.

## One thing the protocol gets wrong about its own source

X.4 and X.6 justify treating the pairwise task as primary on the grounds that
Luera et al.'s "pairwise agreement is strong when the two options genuinely
differ, reaching roughly 90 percent for the strongest judges at large score
gaps." The paper's *overall* pairwise accuracy against human preference is
52.96–59.98% (Claude 59.98%, GPT-4o 59.60%); the ~90% figure applies only to
the subset of comparisons where the two UIs were separated by a large human
score gap. That is a much narrower claim than the protocol's phrasing carries.

It does not change the design — pairwise is still the better-behaved of the two
tasks, and this run's own inter-judge α of 0.35 independently says the absolute
scores cannot carry the argument — but the pairwise result here should be read
against ~53–60% baseline alignment, not against 90%. The protocol's numbers for
the absolute task (72–77% within one Likert point, 35–38% exact) match the
paper.

## Still not done

- **No human validation**, as X.4 specifies by design. Everything in X.6 about
  the borrowed instrument stands unchanged, and is the study's main weakness.
- **Static frames only.** The motion extension floated in X.6 is not attempted.
- **One brief.** As specified.
- **Quality per second is computed; quality per dollar is not.** The latency
  join uses the per-model means already in `lith_provider_latency.xlsx`. No
  cost column is given: the benchmark's raw sheet records no token counts, and
  list prices for the full resolved eleven-model matrix are not written down in
  any existing artefact. That join needs a live price check first, so it is
  left undone rather than guessed at.
- **`gpt-5.5`'s latency figure is not trustworthy and is flagged in the
  results.** The source sheet gives 0.193 s mean with a 0.012 s standard
  deviation over nine calls — an order of magnitude faster than everything else
  and implausibly consistent. It is carried through unaltered because
  re-measuring it is a separate job, but nothing should be concluded from the
  quality-per-second column for that model until it is.

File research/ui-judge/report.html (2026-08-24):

lith · appendix x

# Tier and the screen

10 models across four providers were asked for the same knapp — a meeting cost meter — and the firmware each one wrote was run until it drew. These are the screens, and what three MLLM judges made of them.

builds

19

compiled first pass

5/19

compiled as deployed

15/19

frames captured

90

factor ratings

2268

## The finding, before any judge

The same brief, the same six moments, the same panel. Above, the highest-scoring build in the corpus; below, the lowest. Every screen on this page is the firmware’s own output, drawn by the real LovyanGFX at the panel’s native 320×170 and RGB565, then shown here at 1:1.

highest claude-opus-5 high · mean of nine factors 5.62

boot / idle

anthropic_claude-opus-5_rep2 at started

started

5 min

30 min

90 min

anthropic_claude-opus-5_rep2 at stopped

stopped

lowest claude-haiku-4-5-20251001 low · mean of nine factors 3.24

boot / idle

started

5 min

anthropic_claude-haiku-4-5-20251001_rep2 at 30 min

30 min

90 min

stopped

## Gate 1 · does it compile

Reported twice. First pass is the model’s opening sketch, which is what the protocol asks for. As deployed is after Oldowan’s hidden repair loop — up to three passes, with the compiler errors fed back as [internal] messages the user never sees. A workshop participant only ever meets the second number.

provider | tier | builds | first pass | as deployed
anthropic | low | 2 | 0 | 2
anthropic | high | 2 | 0 | 2
deepseek | low | 1 | 0 | 1
deepseek | high | 2 | 0 | 2
groq | low | 2 | 0 | 0
groq | mid | 2 | 0 | 1
groq | high | 2 | 2 | 2
openai | low | 2 | 1 | 2
openai | mid | 2 | 0 | 1
openai | high | 2 | 2 | 2
all | | 19 | 5 26% | 15 79%

fig. 01 · compile success by provider and tier. The repair loop is the single largest effect anywhere in this study.

## Gates 2–3 · every build, every state

Each build was compiled against the real display library with the ST7789-on-SPI replaced by a RAM framebuffer, then driven down one scripted journey: boot, start the meeting, five minutes, thirty, ninety, stop. The journey comes from the brief, not from each build’s own idea of its controls, so every build is scored on the same route.

build | boot / idle | started | 5 min | 30 min | 90 min | stopped

anthropic_claude-haiku-4-5-20251001_rep1 at started

anthropic_claude-haiku-4-5-20251001_rep1 at stopped

claude-haiku-4-5-20251001low rep 16/6 distinct · mean 5.29
claude-haiku-4-5-20251001low rep 26/6 distinct · 2 blank · mean 3.24

anthropic_claude-opus-5_rep1 at 5 min

claude-opus-5high rep 16/6 distinct · mean 5.56
claude-opus-5high rep 26/6 distinct · mean 5.62

deepseek_deepseek-v4-flash_rep2 at boot / idle

deepseek_deepseek-v4-flash_rep2 at 90 min

deepseek-v4-flashlow rep 26/6 distinct · mean 4.23

deepseek_deepseek-v4-pro_rep1 at 5 min

deepseek_deepseek-v4-pro_rep1 at stopped

deepseek-v4-prohigh rep 16/6 distinct · mean 5.15

deepseek_deepseek-v4-pro_rep2 at 30 min

deepseek-v4-prohigh rep 26/6 distinct · mean 5.27

groq_llama-3.3-70b-versatile_rep2 at started

groq_llama-3.3-70b-versatile_rep2 at stopped

llama-3.3-70b-versatilemid rep 26/6 distinct · mean 4.96

groq_openai_gpt-oss-120b_rep1 at 30 min

openai_gpt-oss-120bhigh rep 16/6 distinct · mean 4.20

groq_openai_gpt-oss-120b_rep2 at boot / idle

groq_openai_gpt-oss-120b_rep2 at 90 min

openai_gpt-oss-120bhigh rep 25/6 distinct · mean 5.19

openai_gpt-4o-mini_rep1 at 30 min

gpt-4o-minilow rep 15/6 distinct · mean 4.48

openai_gpt-4o-mini_rep2 at 5 min

openai_gpt-4o-mini_rep2 at stopped

gpt-4o-minilow rep 26/6 distinct · 1 blank · mean 4.21

openai_gpt-4.1_rep1 at 30 min

gpt-4.1mid rep 16/6 distinct · mean 4.63

openai_gpt-5.5_rep1 at started

openai_gpt-5.5_rep1 at stopped

gpt-5.5high rep 16/6 distinct · mean 5.31

openai_gpt-5.5_rep2 at 30 min

openai_gpt-5.5_rep2 at stopped

gpt-5.5high rep 26/6 distinct · mean 5.52

fig. 02 · the whole corpus. Scroll sideways. “Blank” counts frames that are a single flat colour — a screen the build never drew on.

## X.4 · what the judges said

Nine factors from Luera et al., MLLM as a UI Judge, on their 7-point scale and their prompt, with the framing moved from a web usability test to someone meeting a small device screen. Three judges, one per model family.

reliability first

Mean Krippendorff’s α across the nine factors: 0.351. The protocol says plainly that low agreement invalidates the absolute scores, so the Likert numbers below are description, not evidence. The pairwise task is where the weight sits.

tier | builds | mean of nine factors
low | 5 | 4.29
mid | 2 | 4.80
high | 8 | 5.23

fig. 03 · builds are the unit, not frames: six frames of one build are six views of one design.

### Pairwise, within provider

Every pair judged twice with the two builds swapped between the A and B slots. Only agreement across both orderings counts as a preference; a flip is recorded as a tie, never resolved.

judge | decided | ties | higher tier won
claude-sonnet-5 | 806 | 143 | 77%
gpt-4.1 | 863 | 97 | 78%
qwen3.6-27b | 173 | 16 | 83%
pooled | 1842 | 256 | 78%

fig. 04 · cross-tier comparisons only. 50% means no tier effect.

## What this does not show

- No human comparison group, by design. The instrument's alignment with human judgement is borrowed from Luera et al., who validated it on full-size professionally designed web screens. Nothing here establishes that these judges track human perception of these screens.
- Two reps per model, eleven model-tiers, fifteen judged builds. Enough to see a tier-scale difference; not enough to rank adjacent models.
- Six still frames per build. lith's display is animated, and the fluid fill that carries state in the better builds is exactly what a still throws away.
- One brief. Every build answers the same meeting cost meter prompt.
- The judges' own low agreement, above, limits every absolute number on this page.

Full method, and every point where this run departs from the written protocol, are in DEVIATIONS.md beside the data.

Generated from the result CSVs in results/. Frames are the firmware’s own pixels, not mock-ups.

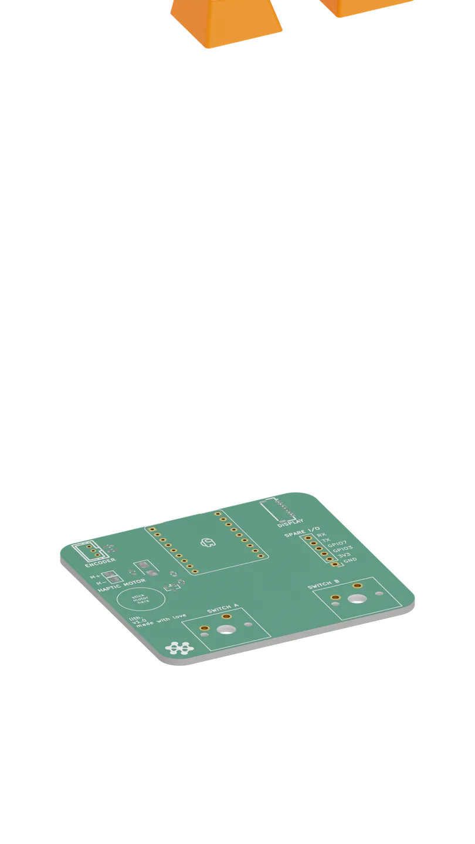
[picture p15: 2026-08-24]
website/assets/frames-pcb/pcb_001.webp

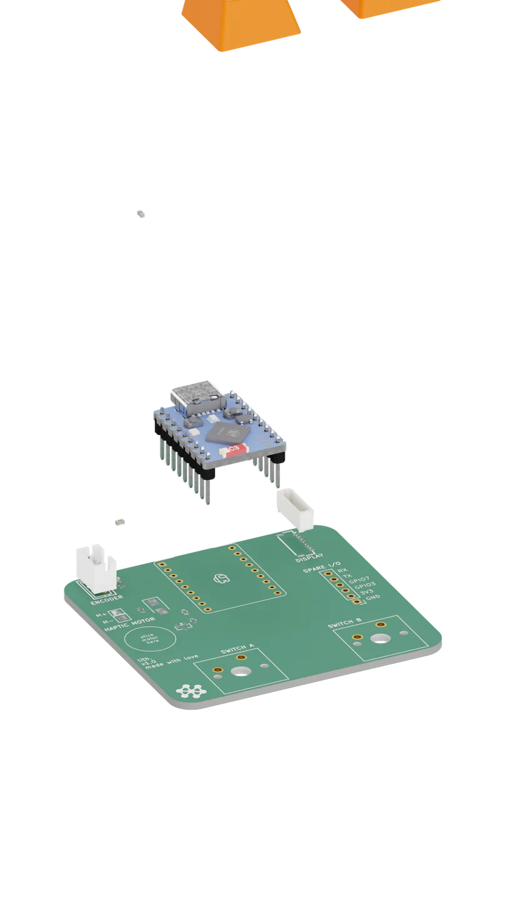
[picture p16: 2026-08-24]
website/assets/frames-pcb/pcb_033.webp

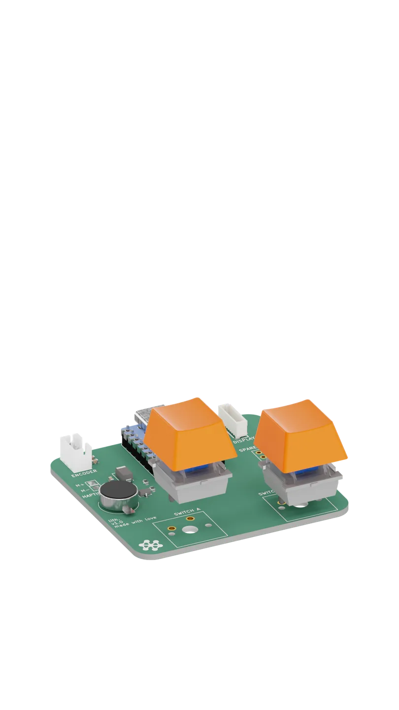
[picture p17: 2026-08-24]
website/assets/frames-pcb/pcb_075.webp

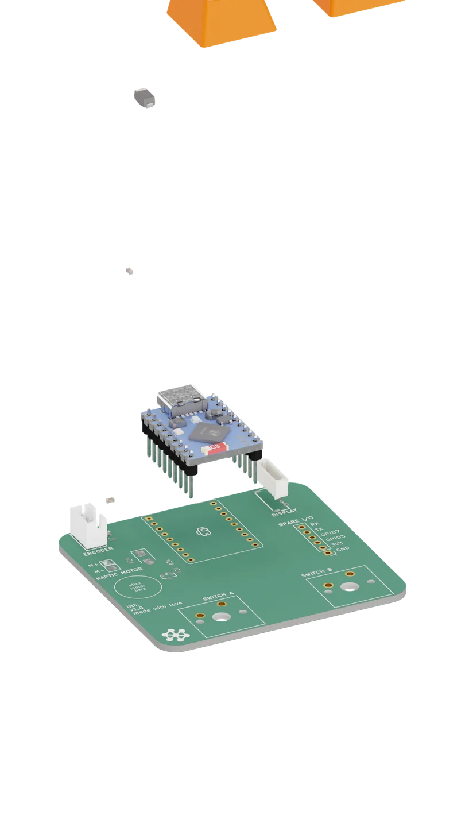
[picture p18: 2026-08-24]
website/assets/frames-pcb/pcb_035.webp

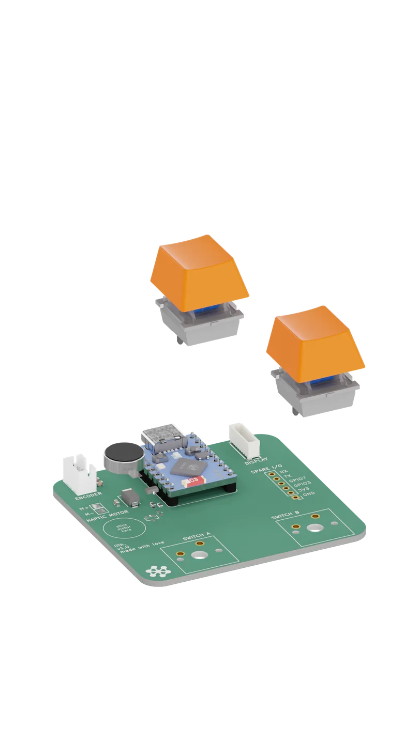
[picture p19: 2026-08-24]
website/assets/frames-pcb/pcb_065.webp

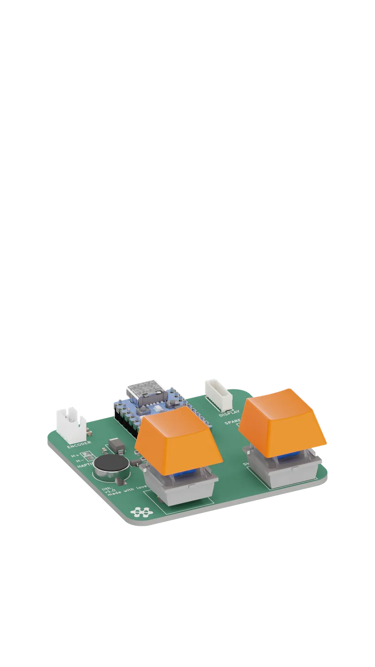
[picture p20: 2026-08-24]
website/assets/frames-pcb/pcb_081.webp

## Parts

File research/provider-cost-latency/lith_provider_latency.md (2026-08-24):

# lith / Oldowan provider benchmark

Latency and list-price comparison across the LLM providers `oldowan.py` (the
lith firmware co-design agent) can run on. Backing data: `lith_provider_latency.xlsx`
(`raw` sheet = every timed call, `latency` sheet = per-model summary).

## Method

Each provider/model is run through the same real 3-turn `oldowan` conversation —
session `0ab8e5ec045142f9a74c3bbd5cda0cac`, the "meeting cost meter" build — taken
verbatim from `lith-backend/sessions/`:

1. *"a meeting cost meter i can start when a meeting starts"*
2. *"silent, just the light"*
3. *"what next?"*

Each turn is timed as a real multi-turn call: the accumulated conversation (system
prompt + prior turns) is sent, the response is timed, then the model's actual
reply is appended before the next turn — not three independent one-shot calls.
This is repeated for **3 reps × 3 turns = 9 timed calls per model**. `mean (s)`
and `stdev (s)` in the summary sheet are across all 9. The replay script is
`lith-backend/bench_latency.py`.

## lith_provider_latency.png — latency by model

Mean wall-clock time per turn, lowest to highest within each provider group.
Error bars are ±1 stdev across the 9 calls.

- **groq** (`llama-3.1-8b-instant`, `llama-3.3-70b-versatile`) is the clear
  latency floor — both models return in well under half a second. This is
  Groq's LPU inference hardware, not a smaller-model effect alone.
- **openai** (`gpt-4.1`, `gpt-4o-mini`) sits in the 1–1.5s range, with
  `gpt-4.1` slightly *faster* than the smaller `gpt-4o-mini` in this run —
  within noise given the stdevs, not a reliable ranking.
- **anthropic** (`claude-haiku-4-5`, `claude-sonnet-5`) is the slowest tier
  here, and also the noisiest: `claude-sonnet-5`'s stdev (1.78s) means real
  turns swing from ~4s to ~8s. This is expected — Sonnet is doing more
  reasoning per turn, not a broken result.
- **deepseek** (`deepseek-chat`, currently served as `deepseek-v4-flash` — see
  note below) lands mid-pack at 4.15s mean, but with the *widest* spread of
  any model tested (stdev 5.89s): two of its three turns were fast
  (1.9–2.6s) and one spiked to 7.9s. One rep is not enough to call this
  reliable — it's flagged as a single-sample outlier, not a verdict on
  DeepSeek's typical latency.

**DeepSeek model note:** `deepseek-chat` is DeepSeek's stable alias — it
currently routes to `deepseek-v4-flash` server-side (confirmed via the API
response's `model` field at benchmark time). If DeepSeek repoints the alias
again, re-run `bench_latency.py deepseek` to refresh.

## lith_provider_cost.png — cost by model

List API pricing per 1M tokens, **not** measured spend from this benchmark
(the raw sheet doesn't record token counts, so this is priced separately from
each provider's public pricing page, checked live while building this chart).
Solid bar = input price, faded bar = output price.

- groq is 15–40x cheaper than everything else on this chart at both the
  input and output rate — consistent with its role here as the fast/cheap
  tier for latency-sensitive turns (e.g. guard-model classification calls
  in `oldowan.py`, which use `llama-3.1-8b-instant`).
- `claude-sonnet-5` ($3 / $15 per 1M) is the most expensive model
  benchmarked, matching its position as the slowest-but-most-capable option.
- deepseek's list price ($0.14 / $0.28) sits just above groq — cheap, but not
  cheap enough to offset its latency variance for a latency-sensitive device
  like lith unless that variance turns out to be a fluke.

## Reading latency and cost together

Groq is unambiguous for anything latency-critical (the guard/adversarial
check in `oldowan.py` already uses `llama-3.1-8b-instant` for this reason).
For the main conversational agent, the real trade is `gpt-4.1` (fast,
mid-price) against `claude-sonnet-5` (slow, high-price, currently the
active provider in `providers.json`) — deepseek is a candidate worth
re-benchmarking with more reps before treating it as a serious third option,
given how much its one bad turn skews its current numbers.

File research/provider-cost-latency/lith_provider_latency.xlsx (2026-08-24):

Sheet: latency
rank | provider | model | turn 1 (s) | turn 2 (s) | turn 3 (s) | mean (s) | stdev (s) | ok / total | tier
1 | groq | llama-3.1-8b-instant | 0.395 | 0.355 | 0.347 | 0.366 | 0.041 | 9/9 | low
2 | groq | llama-3.3-70b-versatile | 0.692 | 0.702 | 0.891 | 0.762 | 0.355 | 9/9 | mid
3 | groq | openai/gpt-oss-120b | 1.519 | 1.077 | 0.913 | 1.17 | 0.72 | 9/9 | top
4 | openai | gpt-4o-mini | 1.505 | 1.281 | 1.154 | 1.313 | 0.48 | 9/9 | low
5 | openai | gpt-4.1 | 1.175 | 1.2 | 1.146 | 1.174 | 0.132 | 9/9 | mid
6 | openai | gpt-5.5 | 0.195 | 0.191 | 0.193 | 0.193 | 0.012 | 9/9 | top
7 | anthropic | claude-haiku-4-5-20251001 | 2.487 | 2.527 | 2.272 | 2.429 | 0.236 | 9/9 | low
8 | anthropic | claude-sonnet-5 | 12.762 | 10.355 | 94.143 | 39.087 | 49.882 | 9/9 | mid
9 | anthropic | claude-opus-5 | 5.59 | 95.814 | 46.877 | 49.427 | 66.138 | 9/9 | top
10 | deepseek | deepseek-v4-flash | 64.526 | 82.177 | 75.2 | 73.968 | 20.019 | 9/9 | low
11 | deepseek | deepseek-v4-pro | 18.382 | 39.464 | 6.638 | 21.495 | 19.781 | 9/9 | top

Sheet: raw
provider | model | rep | turn | latency_s
groq | llama-3.1-8b-instant | 1 | 1 | 0.433132
groq | llama-3.1-8b-instant | 1 | 2 | 0.385795
groq | llama-3.1-8b-instant | 1 | 3 | 0.404344
groq | llama-3.1-8b-instant | 2 | 1 | 0.366697
groq | llama-3.1-8b-instant | 2 | 2 | 0.3177
groq | llama-3.1-8b-instant | 2 | 3 | 0.314273
groq | llama-3.1-8b-instant | 3 | 1 | 0.386076
groq | llama-3.1-8b-instant | 3 | 2 | 0.361745
groq | llama-3.1-8b-instant | 3 | 3 | 0.322791
groq | llama-3.3-70b-versatile | 1 | 1 | 0.695372
groq | llama-3.3-70b-versatile | 1 | 2 | 0.700112
groq | llama-3.3-70b-versatile | 1 | 3 | 0.578813
groq | llama-3.3-70b-versatile | 2 | 1 | 0.689314
groq | llama-3.3-70b-versatile | 2 | 2 | 0.715225
groq | llama-3.3-70b-versatile | 2 | 3 | 1.674645
groq | llama-3.3-70b-versatile | 3 | 1 | 0.692472
groq | llama-3.3-70b-versatile | 3 | 2 | 0.691179
groq | llama-3.3-70b-versatile | 3 | 3 | 0.419937
groq | openai/gpt-oss-120b | 1 | 1 | 2.988772
groq | openai/gpt-oss-120b | 1 | 2 | 0.968933
groq | openai/gpt-oss-120b | 1 | 3 | 0.894028
groq | openai/gpt-oss-120b | 2 | 1 | 0.775244
groq | openai/gpt-oss-120b | 2 | 2 | 0.745345
groq | openai/gpt-oss-120b | 2 | 3 | 0.941488
groq | openai/gpt-oss-120b | 3 | 1 | 0.794401
groq | openai/gpt-oss-120b | 3 | 2 | 1.516719
groq | openai/gpt-oss-120b | 3 | 3 | 0.903359
openai | gpt-4o-mini | 1 | 1 | 2.429669
openai | gpt-4o-mini | 1 | 2 | 1.17669
openai | gpt-4o-mini | 1 | 3 | 1.219555
openai | gpt-4o-mini | 2 | 1 | 1.027739
openai | gpt-4o-mini | 2 | 2 | 1.674871
openai | gpt-4o-mini | 2 | 3 | 0.882684
openai | gpt-4o-mini | 3 | 1 | 1.056119
openai | gpt-4o-mini | 3 | 2 | 0.990179
openai | gpt-4o-mini | 3 | 3 | 1.361156
openai | gpt-4.1 | 1 | 1 | 1.221595
openai | gpt-4.1 | 1 | 2 | 1.204278
openai | gpt-4.1 | 1 | 3 | 1.343164
openai | gpt-4.1 | 2 | 1 | 1.277678
openai | gpt-4.1 | 2 | 2 | 1.335687
openai | gpt-4.1 | 2 | 3 | 1.088164
openai | gpt-4.1 | 3 | 1 | 1.024869
openai | gpt-4.1 | 3 | 2 | 1.06086
openai | gpt-4.1 | 3 | 3 | 1.007947
openai | gpt-5.5 | 1 | 1 | 0.196768
openai | gpt-5.5 | 1 | 2 | 0.209835
openai | gpt-5.5 | 1 | 3 | 0.189985
openai | gpt-5.5 | 2 | 1 | 0.193826
openai | gpt-5.5 | 2 | 2 | 0.172607
openai | gpt-5.5 | 2 | 3 | 0.181152
openai | gpt-5.5 | 3 | 1 | 0.194058
openai | gpt-5.5 | 3 | 2 | 0.190781
openai | gpt-5.5 | 3 | 3 | 0.207199
anthropic | claude-haiku-4-5-20251001 | 1 | 1 | 2.56174
anthropic | claude-haiku-4-5-20251001 | 1 | 2 | 2.098633
anthropic | claude-haiku-4-5-20251001 | 1 | 3 | 2.221553
anthropic | claude-haiku-4-5-20251001 | 2 | 1 | 2.393729
anthropic | claude-haiku-4-5-20251001 | 2 | 2 | 2.7112
anthropic | claude-haiku-4-5-20251001 | 2 | 3 | 2.438039
anthropic | claude-haiku-4-5-20251001 | 3 | 1 | 2.50558
anthropic | claude-haiku-4-5-20251001 | 3 | 2 | 2.769854
anthropic | claude-haiku-4-5-20251001 | 3 | 3 | 2.156985
anthropic | claude-sonnet-5 | 1 | 1 | 9.20396
anthropic | claude-sonnet-5 | 1 | 2 | 9.76037
anthropic | claude-sonnet-5 | 1 | 3 | 150.102162
anthropic | claude-sonnet-5 | 2 | 1 | 13.44996
anthropic | claude-sonnet-5 | 2 | 2 | 11.38846
anthropic | claude-sonnet-5 | 2 | 3 | 38.445872
anthropic | claude-sonnet-5 | 3 | 1 | 15.632094
anthropic | claude-sonnet-5 | 3 | 2 | 9.914885
anthropic | claude-sonnet-5 | 3 | 3 | 93.881786
anthropic | claude-opus-5 | 1 | 1 | 5.060673
anthropic | claude-opus-5 | 1 | 2 | 5.946784
anthropic | claude-opus-5 | 1 | 3 | 130.770352
anthropic | claude-opus-5 | 2 | 1 | 6.758239
anthropic | claude-opus-5 | 2 | 2 | 147.086354
anthropic | claude-opus-5 | 2 | 3 | 5.478117
anthropic | claude-opus-5 | 3 | 1 | 4.952272
anthropic | claude-opus-5 | 3 | 2 | 134.409976
anthropic | claude-opus-5 | 3 | 3 | 4.383772
deepseek | deepseek-v4-flash | 1 | 1 | 77.787018
deepseek | deepseek-v4-flash | 1 | 2 | 84.191955
deepseek | deepseek-v4-flash | 1 | 3 | 82.902715
deepseek | deepseek-v4-flash | 2 | 1 | 26.523745
deepseek | deepseek-v4-flash | 2 | 2 | 88.064357
deepseek | deepseek-v4-flash | 2 | 3 | 83.788606
deepseek | deepseek-v4-flash | 3 | 1 | 89.266014
deepseek | deepseek-v4-flash | 3 | 2 | 74.275872
deepseek | deepseek-v4-flash | 3 | 3 | 58.90905
deepseek | deepseek-v4-pro | 1 | 1 | 12.795546
deepseek | deepseek-v4-pro | 1 | 2 | 66.631776
deepseek | deepseek-v4-pro | 1 | 3 | 5.791754
deepseek | deepseek-v4-pro | 2 | 1 | 18.472363
deepseek | deepseek-v4-pro | 2 | 2 | 13.822985
deepseek | deepseek-v4-pro | 2 | 3 | 9.278919
deepseek | deepseek-v4-pro | 3 | 1 | 23.878502
deepseek | deepseek-v4-pro | 3 | 2 | 37.938075
deepseek | deepseek-v4-pro | 3 | 3 | 4.843341

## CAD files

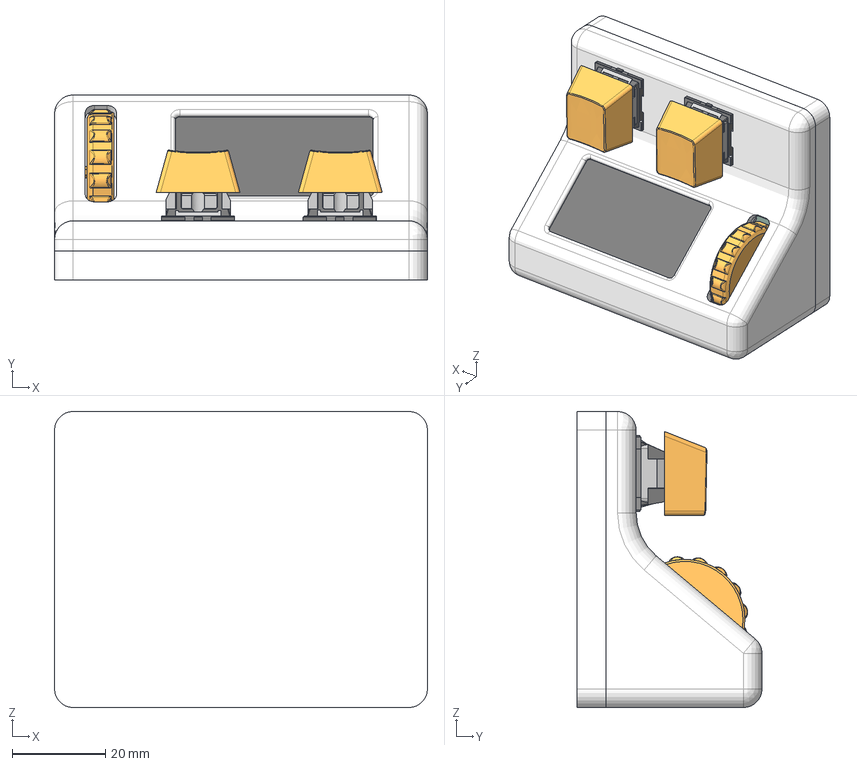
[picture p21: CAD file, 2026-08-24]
cad/lith_assy_v1.step
80.0 x 39.7 x 63.5 mm

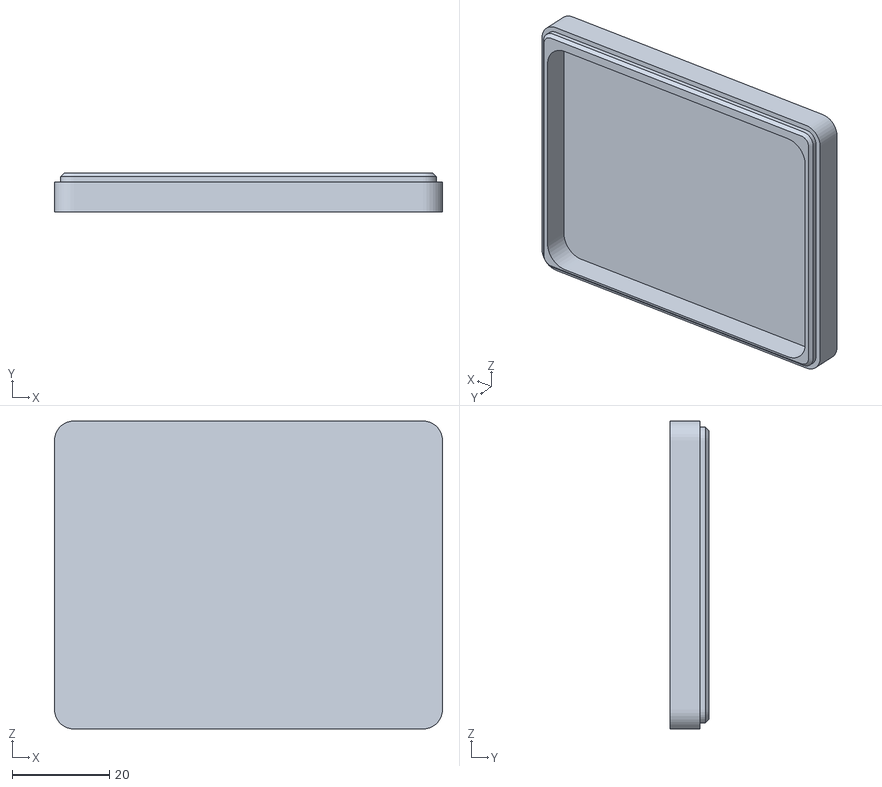
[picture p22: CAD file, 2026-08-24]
cad/mechanical/enclosure_bottom.stl
80.0 x 8.00 x 63.5

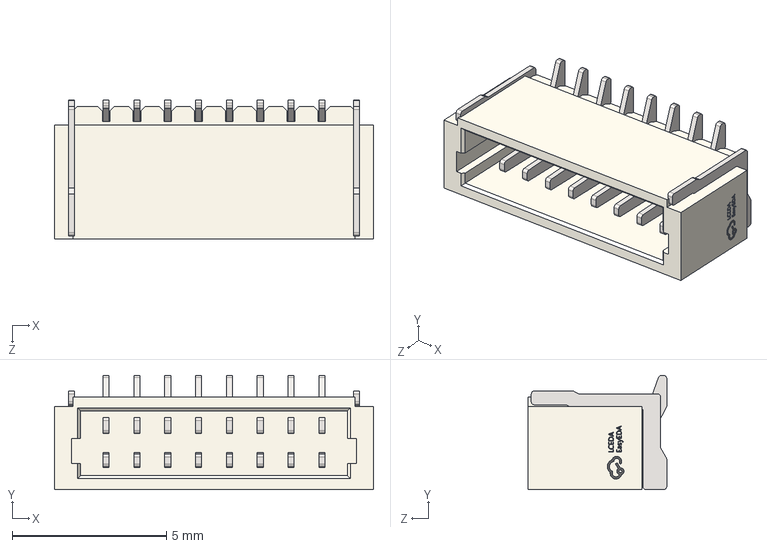
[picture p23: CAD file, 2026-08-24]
cad/pcb/v1.1/CONN-SMD_8P-P1.00_XUNPU_WAFER-100L-8P.step
10.4 x 3.70 x 4.50 mm

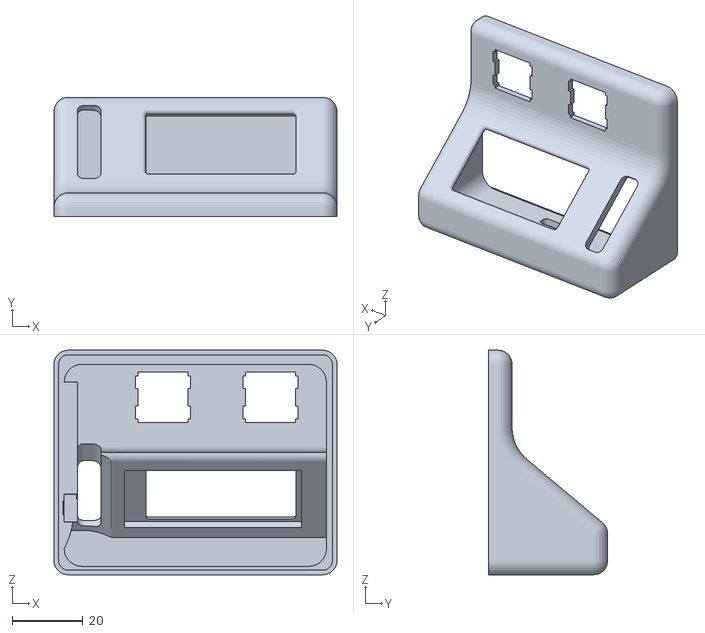
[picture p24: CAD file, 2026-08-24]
cad/mechanical/enclosure_top.stl
80.0 x 33.7 x 63.5

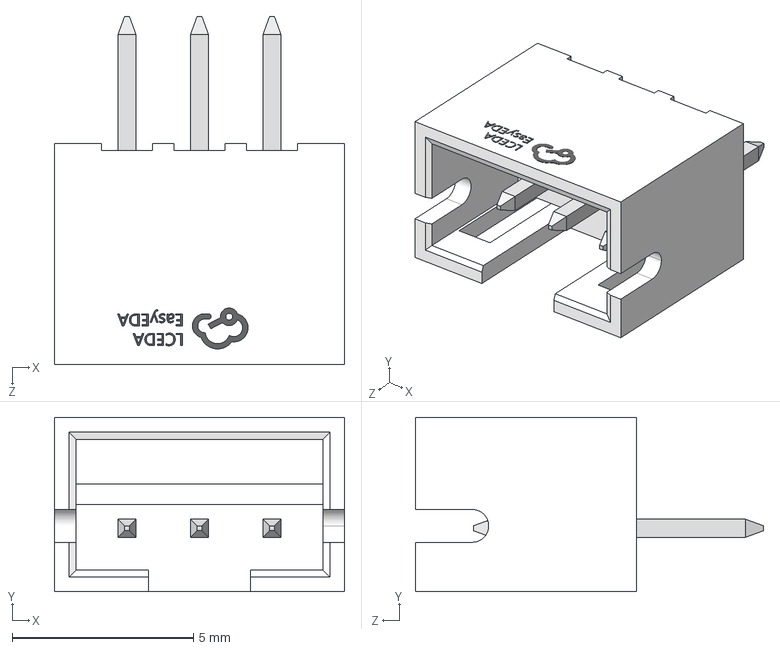
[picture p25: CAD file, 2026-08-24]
cad/pcb/v1.1/CONN-TH_3P-P2.00_HX-2.0MM-3P-ZZ-MS.step
8.00 x 4.81 x 9.60 mm

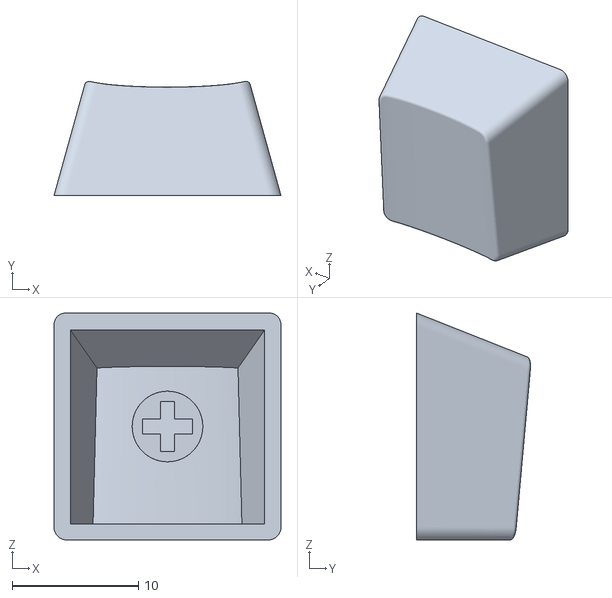
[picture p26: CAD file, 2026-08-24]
cad/mechanical/keycap.stl
18.0 x 9.04 x 18.0

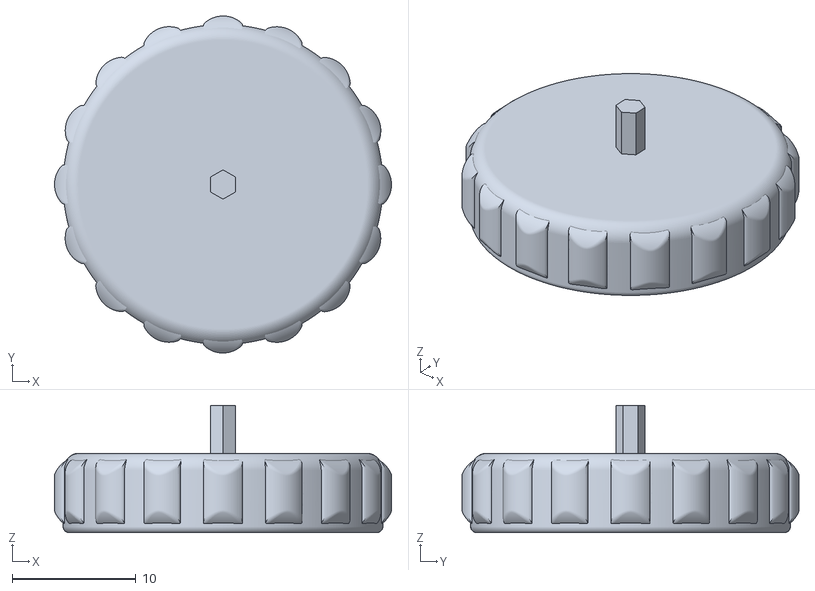
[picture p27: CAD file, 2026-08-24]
cad/mechanical/encoder_wheel.stl
27.2 x 27.2 x 10.2

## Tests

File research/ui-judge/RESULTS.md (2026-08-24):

# Appendix X, results: MLLM-judged UI quality of `oldowan` firmware output across provider tiers

Run 2026-08-16. Read `DEVIATIONS.md` before quoting anything here; the two
largest departures from the protocol are that the corpus has two generation
reps rather than three, and that Gate 1 is reported twice — once as the
protocol defines it, once as a user actually experiences it.

The resolved matrix is **10 model-tiers** across four providers, 19 first-pass
builds, 15 as-deployed builds, 90 captured frames.

| Provider | Low | Mid | High |
|---|---|---|---|
| anthropic | `claude-haiku-4-5-20251001` ×2 | *(no builds in corpus)* | `claude-opus-5` ×2 |
| openai | `gpt-4o-mini` ×2 | `gpt-4.1` ×2 | `gpt-5.5` ×2 |
| groq | `llama-3.1-8b-instant` ×2 | `llama-3.3-70b-versatile` ×2 | `openai/gpt-oss-120b` ×2 |
| deepseek | `deepseek-v4-flash` ×1 | *(none served)* | `deepseek-v4-pro` ×2 |

**The mid tier is the weak point of this run and every mid-tier number below
should be read with that in mind.** Two of the four providers contribute no mid
build at all: deepseek serves no mid model, and the corpus inherited from the
provider benchmark contains no `claude-sonnet-5` sketches. Of the four mid
builds that do exist, two survive to be judged. Any statement about the mid
tier here rests on n = 2, from two providers.

---

## X.1 Gate 1 — compile

**First pass: 5/19 (26%). As deployed, after the hidden repair loop: 15/19
(79%).**

| provider | tier | builds | first pass | as deployed |
|---|---|---:|---:|---:|
| anthropic | low | 2 | 0 | 2 |
| anthropic | high | 2 | 0 | 2 |
| deepseek | low | 1 | 0 | 1 |
| deepseek | high | 2 | 0 | 2 |
| groq | low | 2 | 0 | 0 |
| groq | mid | 2 | 0 | 1 |
| groq | high | 2 | 2 | 2 |
| openai | low | 2 | 1 | 2 |
| openai | mid | 2 | 0 | 1 |
| openai | high | 2 | 2 | 2 |

Pooled across providers, as-deployed compile is 71% at the low tier, 50% at the
mid, and **100% at the high tier**. The four builds that never compile at all
are both `llama-3.1-8b-instant` reps, one `llama-3.3-70b-versatile` rep, and one
`gpt-4.1` rep. All four exhaust all three repair passes still failing, which is
a stronger statement than failing once: a model that cannot fix its own sketch
given the compiler's own errors, three times over, is not merely slower to
converge.

Everything that does compile as-deployed does so on pass 1 or 2 — no build in
the corpus was rescued by the third attempt. Whatever `MAX_ATTEMPTS = 3` is
buying in production, on this brief it is not the third pass.

### The first-pass number is not a clean measure of the model

Three builds — `claude-opus-5` rep1 and rep2, and `deepseek-v4-pro` rep2 — are
rejected by `arduino-cli` and yet compile and run correctly in the Gate 2
harness. Their errors are all the same shape:

```
'BtnEvent' does not name a type
'RGB' was not declared in this scope
variable or field 'pollButton' declared void
```

This is the Arduino builder's own prototype generation. A `.ino` is not a C++
translation unit, so `arduino-cli` synthesises a forward declaration for every
function and inserts them at the top of the file — above the `struct` and
`enum` declarations those signatures mention. A sketch that defines a type and
then takes it as a parameter is valid C++ and is broken by the tool that builds
it. The Gate 2 harness generates the same prototypes but places them after the
last type declaration, and those three builds are fine.

All three are high-tier builds, which is not a coincidence: writing a `struct
Button` and a `void pollButton(Button&)` is a thing the more capable models do
and the weaker ones do not. **The first-pass compile rate therefore penalises
the high tier for a toolchain defect**, and the as-deployed number — where the
repair loop simply works around it — is both the fairer measure and the one a
user meets.

---

## X.2 Gates 2–3 — render and journey coverage

All 15 as-deployed builds compiled against the harness, ran to completion, and
produced all six frames: **90/90 frames captured, no absences.** Every build
called `setRotation`, so none of them drew portrait on a landscape panel.

Journey coverage, counted as *distinct* frames among the six:

| tier | builds | mean distinct (of 6) |
|---|---:|---:|
| low | 5 | 5.80 |
| mid | 2 | 6.00 |
| high | 8 | 5.88 |

**There is no tier effect in coverage** (Jonckheere–Terpstra z = 0.17,
p = 0.87). Every build in the corpus, weakest to strongest, distinguishes
essentially all six states of the journey. Two builds collapse one pair of
states — `gpt-oss-120b` rep2 and `gpt-4o-mini` rep1 each show 5 distinct frames
— and that is the whole of it.

This is worth stating plainly because the protocol expected coverage to be a
discriminator: "a build that only ever shows one screen has failed the brief
regardless of how that screen scores." No build in this corpus fails that way.
Once a sketch compiles, it answers the brief structurally. Whatever separates
the tiers is not *whether* the states are distinguished but *how they look*.

Two builds do draw screens with nothing on them — `claude-haiku-4-5` rep2 has
two flat-colour frames and `gpt-4o-mini` rep2 has one, three in all — which the
harness counts separately from an absent frame, since a judge shown a blank
panel is scoring nothing at all.

---

## X.3 What the screens actually show

Before any judge, the contact sheet (`results/contact_sheet.png`, and the
report page) separates the corpus visually, and the separation runs along the
device's own documented design language rather than along general graphic
taste. `device_profile.json` tells every model the same rules: one focal
element, two type sizes, no boxes or panel chrome, a bare near-black canvas
with a single off-white ink, and colour carrying meaning while touching as
little of the screen as possible.

- `claude-opus-5` (both reps) builds the ambient fluid fill that *is* the
  state: a liquid level rising through the panel, teal to amber to red as cost
  accumulates, with one large number and one letter-spaced label above it. It
  is the only build in the corpus that uses an animation to replace a number
  rather than to decorate one.
- `gpt-5.5` (both reps) renders a seven-segment number with a single thin
  accent rule beneath it that changes colour at the threshold. Restrained and
  legible.
- `gpt-oss-120b` rep1 floods the entire panel cyan, then orange, with magenta
  text on top. `llama-3.3-70b-versatile` rep2 floods it blue with magenta text.
  Both invert the rule they were given: colour covers everything and means
  nothing.
- `gpt-4o-mini` rep1 overflows the panel. At thirty minutes it renders
  `Cost:  $2` with the `9` wrapped onto the next line and overlapping
  `Duration: 29 min`. The number the whole device exists to show is unreadable
  at exactly the moment it matters.
- `deepseek-v4-flash` shows a green dot that grows and brightens. Its render
  path contains no text call of any kind — only `fillCircle` — so the cost is
  never displayed as a number anywhere in the journey. That is arguably a
  literal reading of turn 2 of the brief, *"silent, just the light"*, rather
  than a failure: the instruction was about suppressing the haptics, and the
  model took it as a description of the whole display. It is the one build in
  the corpus where the ambiguity of the user's own words, not the model's
  competence, best explains the screen — and it is also the cleanest
  demonstration that journey coverage says nothing about whether the brief was
  answered, since it distinguishes all six states while showing no cost at all.

---

## X.4 Judging

Three judges: `claude-sonnet-5`, `gpt-4.1`, and `qwen/qwen3.6-27b` on Groq —
one per model family, all vision-capable. Nine factors, 7-point scale, Luera
et al.'s Figure 7 prompt with the framing moved to a small embedded display.
Median of three repetitions per judge per frame.

Coverage is uneven and worth stating before the numbers. `claude-sonnet-5` and
`gpt-4.1` returned a complete nine-factor score on all 90 frames.
`qwen3.6-27b` returned one on **72 of 90**: it reasons in an unsuppressable
`<think>` block that frequently consumed its whole token budget before it
answered, and 18 frames have no usable rep at all. Its medians also rest on
fewer reps — 45 of its 90 frames are a median over one rep rather than three.
The open-weight judge is therefore the thinnest of the three, and its results
should be read as such.

### Reliability first

**Mean Krippendorff's α across the nine factors: 0.35.** By factor:

| factor | α |
|---|---:|
| visual hierarchy | 0.46 |
| interest | 0.45 |
| aesthetic pleasure | 0.42 |
| comfort | 0.38 |
| clarity | 0.36 |
| intuitive | 0.32 |
| ease of use | 0.31 |
| memorable | 0.27 |
| trust | 0.20 |

The protocol is explicit that low agreement invalidates the absolute scores,
and 0.35 is low by any conventional reading. **The Likert numbers below are
therefore descriptive only.** Three judges looking at the same 320×170 panel
do not agree on how trustworthy or memorable it is, and no amount of averaging
fixes that.

Note which factors hold up best: visual hierarchy, interest and aesthetic
pleasure — the ones answerable from the arrangement of the pixels. The ones
that collapse — trust at 0.20, memorable at 0.27 — are the ones that require
imagining a person's relationship with a device the judge has never held.
Luera et al. already flagged ease of use as near-random in their own pairwise
data; on this instrument it is one of the weaker three here too.

### Absolute scores, as description

Mean of the nine factors, builds as the unit of analysis (six frames of one
build are six views of one design, not six independent draws):

| tier | builds | mean of nine factors |
|---|---:|---:|
| low | 5 | 4.29 |
| mid | 2 | 4.80 |
| high | 8 | 5.23 |

Jonckheere–Terpstra ordinal trend: **z = +2.44, p = 0.015** (n = 15 builds).
Running the same test over the 252 frame-level rows returns z = +6.98,
p < 0.001; that number is reported here only to show how much treating nested
frames as independent inflates it.

Per factor, all three judges independently find a significant upward trend on
**visual hierarchy** (p = 0.008 / 0.009 / 0.031), **memorable**
(0.009 / 0.020 / 0.011) and **interest** (0.003 / 0.007 / 0.008); two of three
also find one on **aesthetic pleasure**. None of the three finds a trend on
**clarity**, **trust**, **intuitive** or **ease of use**. Clarity is the
instructive one: it scores 6.0–6.9 for every tier, because "the layout is
uncluttered" rewards an empty screen. `gpt-oss-120b`'s full-screen orange panel
with magenta text was scored 7/7 for clarity by `claude-sonnet-5` —
"only two lines of text on a plain background, extremely uncluttered" — while
scoring 3/7 for aesthetic pleasure in the same reply. The factor is measuring
sparseness, not design, and on a device whose whole idiom is sparseness it
cannot discriminate.

The single largest number in the table is not a tier effect at all.
`claude-haiku-4-5` rep1 scores **5.29** and rep2 scores **3.24** — the same
model, the same brief, two draws. That 2.05-point gap is larger than the whole
low-to-high tier difference of 0.94. Rep-to-rep variance within a model
exceeds the effect the study set out to measure, which is the strongest
argument in this run for the protocol's own "small n" caveat.

### Pairwise, the primary evidence

Every within-provider pair was judged twice, with the two builds swapped
between the UI-A and UI-B slots. Only agreement across both orderings counts;
a flip is recorded as a tie and never resolved. Position consistency was 84%
overall — real position bias, but modest — and the tie rate runs from 8%
(`qwen3.6-27b`) to 15% (`claude-sonnet-5`).

On cross-tier comparisons, the **higher tier won 77.8% of decided comparisons**
(n = 1842). All three judges agree, and they agree criterion by criterion:

| criterion | pooled | sonnet-5 | gpt-4.1 | qwen3.6 |
|---|---:|---:|---:|---:|
| visual hierarchy | **0.89** | 0.92 | 0.88 | 0.82 |
| memorable | 0.80 | 0.77 | 0.83 | 0.79 |
| interest | 0.79 | 0.76 | 0.82 | 0.78 |
| overall preference | 0.78 | 0.81 | 0.75 | 0.83 |
| ease of use | 0.77 | 0.78 | 0.75 | 0.83 |
| intuitive | 0.77 | 0.79 | 0.75 | 0.82 |
| clarity | 0.76 | 0.76 | 0.75 | 0.83 |
| trust | 0.75 | 0.72 | 0.76 | 0.83 |
| aesthetic pleasure | 0.75 | 0.71 | 0.77 | 0.88 |
| comfort | 0.70 | 0.64 | 0.72 | 0.93 |

`qwen3.6-27b` contributed 319 of a possible 1320 comparisons — the same
budget-exhaustion that thinned its absolute scores — so its column is noisier
than the other two and its high figures on comfort and aesthetic pleasure rest
on few decisions. The two full columns are the ones to weight.

Visual hierarchy is the discriminator, at 0.89 pooled and 0.92 for the judge
with the most data — which is exactly what the
contact sheet shows: the separation between tiers is one focal element against
a bare ground versus a flooded panel or an overflowing line of text. It is also
the factor with the highest inter-judge agreement, so the two analyses point the
same way.

---

## X.5 The two questions the study asked

**1. Does model tier predict the perceived quality of the on-device UI that
`oldowan` generates?**

Yes, on this instrument, and mostly through one channel.

- It does **not** predict whether the build answers the brief structurally.
  Coverage of the six journey states is flat across tiers (p = 0.87); every
  build that compiles distinguishes essentially all six.
- It **does** predict which of two builds a judge prefers: 77.8% of decided
  cross-tier comparisons go to the higher tier (n = 1842), and all three judges
  agree criterion by criterion.
- The channel is **visual hierarchy** — 0.89 pairwise, the strongest ordinal
  trend in the absolute scores, and the factor with the best inter-judge
  agreement. What separates the tiers is one focal element on a bare ground
  versus a flooded panel or a line of text that runs off the edge.
- The effect is **smaller than the within-model spread**. Two reps of
  `claude-haiku-4-5` differ by 2.05 points on the nine-factor mean; the
  low-to-high tier difference is 0.94.

**2. Is the tier difference large enough to justify the latency and cost
penalty of the higher tiers?**

On latency, mostly no — and the exceptions are not where the tier story would
put them.

| model | tier | mean of nine factors | mean s/turn | quality per second |
|---|---|---:|---:|---:|
| gpt-5.5 | high | 5.42 | 0.19 | 28.1 |
| llama-3.3-70b-versatile | mid | 4.96 | 0.76 | 6.5 |
| gpt-4.1 | mid | 4.63 | 1.17 | 3.9 |
| gpt-4o-mini | low | 4.34 | 1.31 | 3.3 |
| claude-haiku-4-5 | low | 4.27 | 2.43 | 1.8 |
| deepseek-v4-pro | high | 5.21 | 21.50 | 0.24 |
| claude-opus-5 | high | 5.59 | 49.43 | 0.11 |
| deepseek-v4-flash | low | 4.23 | 73.97 | 0.06 |

`claude-opus-5` produces the best screens in the corpus and takes roughly 260
times as long per turn as `gpt-5.5` to produce screens scoring 0.16 lower — a
difference well inside the within-model spread. On this evidence the case for
the top Anthropic tier is not the UI it draws.

Two cautions on that table. `gpt-5.5`'s 0.19 s mean comes straight from
`lith_provider_latency.xlsx` and is anomalous enough — an order of magnitude
faster than every other model, with a 0.012 s standard deviation across nine
calls — that it should be re-measured before anyone acts on it. And no
cost column is given: the benchmark's raw sheet records no token counts, and
list prices for the full resolved matrix are not written down in any existing
artefact, so quality-per-dollar is left undone rather than guessed.

The more useful finding for `oldowan` sits in Gate 1, not in the judging. The
repair loop moves compile success from 26% to 79% — an effect several times
larger than anything tier does to the screens, and it is a property of the
harness rather than of the model. Whatever tier `oldowan` runs on, the thing
most worth protecting is the loop that never shows a compile error to the
user.

---

## X.6 Limitations of this run

Everything in the protocol's own X.6 stands unchanged: no human validation, an
instrument borrowed from full-size web screens and applied to a 320×170
glanceable panel, static frames that discard the animation which is the best
builds' whole idea, and one brief. Added by this run:

- **Inter-judge agreement is low (α = 0.35).** By the protocol's own rule this
  invalidates the absolute scores; they are reported as description and the
  pairwise result carries the argument.
- **The open-weight judge is thin.** `qwen3.6-27b` produced usable absolute
  scores on 72 of 90 frames, half of them from a single rep, and 319 of a
  possible 1320 pairwise comparisons. It agrees with the other two on
  direction, but it is not an equal third vote.
- **The mid tier has two builds, from two providers.** deepseek serves no mid
  model, the corpus contains no `claude-sonnet-5` sketches at all, and of the
  four mid builds that exist only one `llama-3.3-70b-versatile` and one
  `gpt-4.1` survived to be judged. Every mid-tier number here rests on n = 2,
  and the low/mid/high split of judged builds is 5 / 2 / 8. A trend test over
  three groups where the middle one has two members is being carried by its
  endpoints; the low-versus-high contrast is the part to trust.
- **Two reps, not three**, and rep-to-rep variance turned out to exceed the
  tier effect — so this is the limitation that matters most for anyone wanting
  to act on the result.

The `gpt-oss-120b` row is missing from the table above because its own
quality-per-second (4.00, from 1.17 s/turn) sits mid-pack and adds nothing to
the argument; it is in `results/analysis.txt` with everything else.

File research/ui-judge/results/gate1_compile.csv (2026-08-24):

build_id | provider | tier | model | rep | code_bytes | static_check_ok | compiled | compile_s | error_summary
anthropic_claude-haiku-4-5-20251001_rep1 | anthropic | low | claude-haiku-4-5-20251001 | 1 | 5453 | True | False | 24.91 | /tmp/gate1_kbrq87eo/knapp/knapp.ino:171:26: error: 'Font7_GLCD_M' is not a member of 'fonts' /tmp/gate1_kbrq87eo/knapp/knapp.ino:201:3: error: 'ledcSetup' was not declared in this scope /tmp/gate1_kbrq87eo/knapp/knapp.ino:202:3: error: 'ledcAttachPin' was not declared in this scope; did you mean 'ledcAttach'?
anthropic_claude-haiku-4-5-20251001_rep2 | anthropic | low | claude-haiku-4-5-20251001 | 2 | 6757 | True | False | 23.88 | /tmp/gate1_0dpuljso/knapp/knapp.ino:54:23: error: no matching function for call to 'lgfx::v1::LGFX_Sprite::LGFX_Sprite(LGFX&)' /tmp/gate1_0dpuljso/knapp/knapp.ino:212:56: error: 'CC_DATUM' is not a member of 'lgfx::v1::textdatum::textdatum_t' /tmp/gate1_0dpuljso/knapp/knapp.ino:217:57: error: 'CC_DATUM' is not a member of 'lgfx::v1::textdatum::textdatum_t' /tmp/gate1_0dpuljso/knapp/knapp.ino:226:5
anthropic_claude-opus-5_rep1 | anthropic | high | claude-opus-5 | 1 | 12019 | True | False | 25.89 | /tmp/gate1_mnr6g3wi/knapp/knapp.ino:83:1: error: 'BtnEvent' does not name a type
anthropic_claude-opus-5_rep2 | anthropic | high | claude-opus-5 | 2 | 11917 | True | False | 25.53 | /tmp/gate1_v9etu5lu/knapp/knapp.ino:76:26: error: 'RGB' was not declared in this scope /tmp/gate1_v9etu5lu/knapp/knapp.ino:76:33: error: expected primary-expression before 'float' /tmp/gate1_v9etu5lu/knapp/knapp.ino:76:40: error: expression list treated as compound expression in initializer [-fpermissive] /tmp/gate1_v9etu5lu/knapp/knapp.ino:100:27: error: 'Btn' was not declared in this scope /tmp/
deepseek_deepseek-v4-flash_rep2 | deepseek | low | deepseek-v4-flash | 2 | 8252 | True | False | 24.09 | /tmp/gate1_4gqu_ii0/knapp/knapp.ino:141:15: error: 'using LGFX_Sprite = class lgfx::v1::LGFX_Sprite' {aka 'class lgfx::v1::LGFX_Sprite'} has no member named 'created'; did you mean 'createPng'? /tmp/gate1_4gqu_ii0/knapp/knapp.ino:155:28: error: 'FreeSansBold36pt7b' is not a member of 'fonts'
deepseek_deepseek-v4-pro_rep1 | deepseek | high | deepseek-v4-pro | 1 | 8161 | True | False | 2.38 | /tmp/gate1_xtl7jdlo/knapp/knapp.ino:2:10: fatal error: LGFX.hpp: No such file or directory
deepseek_deepseek-v4-pro_rep2 | deepseek | high | deepseek-v4-pro | 2 | 7484 | True | False | 25.23 | /tmp/gate1_cavyrawt/knapp/knapp.ino:94:6: error: variable or field 'pollButton' declared void /tmp/gate1_cavyrawt/knapp/knapp.ino:94:17: error: 'Button' was not declared in this scope /tmp/gate1_cavyrawt/knapp/knapp.ino:94:25: error: 'b' was not declared in this scope
groq_llama-3.1-8b-instant_rep1 | groq | low | llama-3.1-8b-instant | 1 | 2265 | True | False | 24.83 | /tmp/gate1_pqaapyu2/knapp/knapp.ino:12:1: error: 'LGFX' does not name a type /tmp/gate1_pqaapyu2/knapp/knapp.ino:28:3: error: 'tft' was not declared in this scope /tmp/gate1_pqaapyu2/knapp/knapp.ino:34:14: error: expected unqualified-id before '.' token /tmp/gate1_pqaapyu2/knapp/knapp.ino:36:31: error: expected primary-expression before '.' token /tmp/gate1_pqaapyu2/knapp/knapp.ino:40:14: error: e
groq_llama-3.1-8b-instant_rep2 | groq | low | llama-3.1-8b-instant | 2 | 1208 | True | False | 23.07 | /tmp/gate1_w2ufqk_b/knapp/knapp.ino:14:1: error: 'LGFX' does not name a type /tmp/gate1_w2ufqk_b/knapp/knapp.ino:18:3: error: 'tft' was not declared in this scope /tmp/gate1_w2ufqk_b/knapp/knapp.ino:42:5: error: 'tft' was not declared in this scope /tmp/gate1_w2ufqk_b/knapp/knapp.ino:42:20: error: 'LGFX_COLOR_BLACK' was not declared in this scope; did you mean 'LOG_ANSI_COLOR_BLACK'? /tmp/gate1_w2
groq_llama-3.3-70b-versatile_rep1 | groq | mid | llama-3.3-70b-versatile | 1 | 1836 | True | False | 22.75 | /tmp/gate1_nc4ttnm0/knapp/knapp.ino:36:3: error: 'ledcSetup' was not declared in this scope /tmp/gate1_nc4ttnm0/knapp/knapp.ino:37:3: error: 'ledcAttachPin' was not declared in this scope; did you mean 'ledcAttach'? /tmp/gate1_nc4ttnm0/knapp/knapp.ino:54:14: error: expected ';' before ')' token /tmp/gate1_nc4ttnm0/knapp/knapp.ino:54:7: error: statement cannot resolve address of overloaded function
groq_llama-3.3-70b-versatile_rep2 | groq | mid | llama-3.3-70b-versatile | 2 | 2054 | True | False | 21.80 | /tmp/gate1_u5l_plhz/knapp/knapp.ino:84:16: error: expected ';' before ')' token /tmp/gate1_u5l_plhz/knapp/knapp.ino:84:9: error: statement cannot resolve address of overloaded function
groq_openai_gpt-oss-120b_rep1 | groq | high | openai_gpt-oss-120b | 1 | 7492 | True | True | 54.03
groq_openai_gpt-oss-120b_rep2 | groq | high | openai_gpt-oss-120b | 2 | 7404 | True | True | 54.65
openai_gpt-4.1_rep1 | openai | mid | gpt-4.1 | 1 | 7675 | True | False | 21.78 | /tmp/gate1_kkpbykmx/knapp/knapp.ino:65:6: error: variable or field 'pollButton' declared void /tmp/gate1_kkpbykmx/knapp/knapp.ino:65:17: error: 'Button' was not declared in this scope /tmp/gate1_kkpbykmx/knapp/knapp.ino:65:25: error: 'btn' was not declared in this scope /tmp/gate1_kkpbykmx/knapp/knapp.ino:65:37: error: 'onShort' was not declared in this scope /tmp/gate1_kkpbykmx/knapp/knapp.ino:65
openai_gpt-4.1_rep2 | openai | mid | gpt-4.1 | 2 | 7332 | True | False | 23.31 | /tmp/gate1_qyc0fq25/knapp/knapp.ino:199:3: error: 'ledcAttachPin' was not declared in this scope; did you mean 'ledcAttach'? /tmp/gate1_qyc0fq25/knapp/knapp.ino:200:3: error: 'ledcSetup' was not declared in this scope /tmp/gate1_qyc0fq25/knapp/knapp.ino:214:7: error: 'class LGFX' has no member named 'pushSprite' /tmp/gate1_qyc0fq25/knapp/knapp.ino:231:9: error: 'class LGFX' has no member named 'pu
openai_gpt-4o-mini_rep1 | openai | low | gpt-4o-mini | 1 | 2844 | True | True | 52.49
openai_gpt-4o-mini_rep2 | openai | low | gpt-4o-mini | 2 | 2783 | True | False | 22.90 | /tmp/gate1_tfcb_q0l/knapp/knapp.ino:73:21: error: no matching function for call to 'LGFX::setTextColor(int, int, int)'
openai_gpt-5.5_rep1 | openai | high | gpt-5.5 | 1 | 9344 | True | True | 50.68
openai_gpt-5.5_rep2 | openai | high | gpt-5.5 | 2 | 12163 | True | True | 52.95

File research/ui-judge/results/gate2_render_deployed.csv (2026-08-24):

build_id | sim_build_ok | ran_ok | timed_out | init_called | rotation_set | rotation | panel_w | panel_h | loops | motor_writes | frames_present | distinct_frames | blank_frames | ink_1_boot_idle | ink_2_started | ink_3_mid_meeting | ink_4_threshold | ink_5_extended | ink_6_stopped | note
anthropic_claude-haiku-4-5-20251001_rep1 | True | True | 0 | 1 | 1 | 1 | 320 | 170 | 5703 | 4 | 6 | 6 | 0 | 0.0097 | 0.0104 | 0.092 | 0.5016 | 0.0089 | 0.0086
anthropic_claude-haiku-4-5-20251001_rep2 | True | True | 0 | 1 | 1 | 1 | 320 | 170 | 5703 | 4 | 6 | 6 | 2 | 0.0119 | 0.0 | 0.0824 | 0.4941 | 0.0 | 0.0196
anthropic_claude-opus-5_rep1 | True | True | 0 | 1 | 1 | 1 | 320 | 170 | 5708 | 0 | 6 | 6 | 0 | 0.1303 | 0.2495 | 0.5999 | 0.5825 | 0.5046 | 0.51
anthropic_claude-opus-5_rep2 | True | True | 0 | 1 | 1 | 1 | 320 | 170 | 5708 | 0 | 6 | 6 | 0 | 0.0872 | 0.2124 | 0.3603 | 0.4832 | 0.5467 | 0.5463
deepseek_deepseek-v4-flash_rep2 | True | True | 0 | 1 | 1 | 1 | 320 | 170 | 5708 | 0 | 6 | 6 | 0 | 0.0064 | 0.0265 | 0.0291 | 0.0469 | 0.1039 | 0.0058
deepseek_deepseek-v4-pro_rep1 | True | True | 0 | 1 | 1 | 1 | 320 | 170 | 5708 | 0 | 6 | 6 | 0 | 0.0148 | 0.0143 | 0.0165 | 0.0175 | 0.0195 | 0.0174
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

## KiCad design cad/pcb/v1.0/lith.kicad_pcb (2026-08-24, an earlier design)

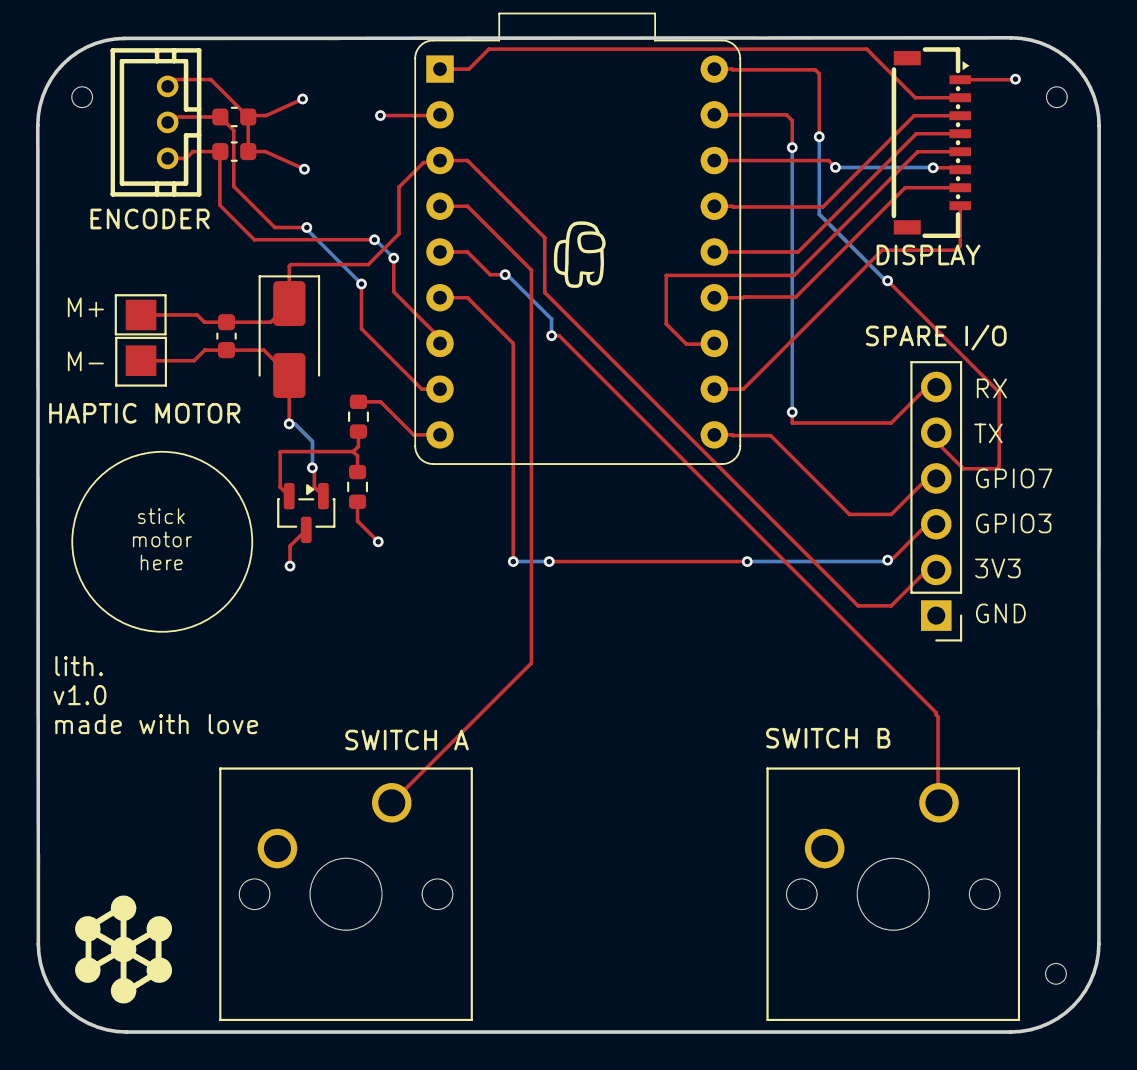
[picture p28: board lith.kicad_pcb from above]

Board: 2 copper layers, 59.0 x 55.2 mm, 14 parts (0 on the bottom side), 20 nets.

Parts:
C1, C2, C3: 100n; C_0603_1608Metric
D1: D; D_SMA
DISPLAY: Conn_01x08_Socket; CONN-SMD_8P-P1.00_XUNPU_WAFER-100L-8P
ENCODER: RotaryEncoder; CONN-TH_3P-P2.00_HX-2.0MM-3P-ZZ-MS
HAPTIC MOTOR: Motor_DC; PinHeader_1x02_P2.54mm_Vertical
Q1: NPN; SOT-23
R1: 1k; R_0603_1608Metric
R2: 10k; R_0603_1608Metric
SPARE I/O: Conn_01x06_Socket; PinHeader_1x06_P2.54mm_Vertical
SWITCH A: SW_Push; SW_Cherry_MX_1.00u_PCB
SWITCH B: SW_Push; SW_Cherry_MX_1.00u_PCB
U1: ESP32-S3-Zero; Waveshare-ESP32-S3-Zero

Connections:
+3V3: C3.1, D1.1 (K), HAPTIC MOTOR.1 (+), SPARE I/O.2, U1.3 (3V3(OUT))
+5V: DISPLAY.2, U1.1 (VDD)
DISP_BLK: DISPLAY.8, U1.11 (GPIO8)
DISP_CS: DISPLAY.7, U1.13 (GPIO10)
DISP_DC: DISPLAY.6, U1.16 (GPIO13)
DISP_RES: DISPLAY.5, U1.12 (GPIO9)
DISP_SCL: DISPLAY.3, U1.15 (GPIO12)
DISP_SDA: DISPLAY.4, U1.14 (GPIO11)
ENCODER_A: C1.1, ENCODER.3, U1.7 (GPIO4)
ENCODER_B: C2.1, ENCODER.2, U1.8 (GPIO5)
GND: C1.2, C2.2, DISPLAY.1, ENCODER.1, Q1.3 (E), R2.2, SPARE I/O.1, SWITCH A.2, SWITCH B.2, U1.2 (GND)
GPIO3: SPARE I/O.3, U1.6 (GPIO3)
GPIO7: SPARE I/O.4, U1.10 (GPIO7)
MOTOR_PWM: R1.1, U1.9 (GPIO6)
Q_B: Q1.2 (B), R1.2, R2.1
Q_C: C3.2, D1.2 (A), HAPTIC MOTOR.2 (-), Q1.1 (C)
RX: SPARE I/O.6, U1.17 (RX)
SW1: SWITCH A.1, U1.4 (GPIO1)
SW2: SWITCH B.1, U1.5 (GPIO2)
TX: SPARE I/O.5, U1.18 (TX)

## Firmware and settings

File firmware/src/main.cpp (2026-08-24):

// =====================================================================
// Lith pomodoro timer — ESP32-S3-Zero
//   ST7789V2 170x320 display (LovyanGFX) + rotary encoder + 2 keyboard switches
//   + vibration motor on an NPN low-side switch
//
// CONTROLS
//   Encoder           -> set the length shown on screen (when idle)
//   SW1 short press   -> start / pause / resume
//   SW1 long  press   -> reset current phase back to full
//   SW2 short press   -> skip to next phase
//   SW2 long  press   -> cycle which setting the encoder edits
//
// SERIAL COMMANDS (115200)
//   s start/pause   r reset   n next phase   f field   + / - adjust
//   q replay splash   ? help
// =====================================================================

// LITH_SIM builds this same file on a PC to render the screen off-device (see
// lith/tools/sim). The simulator supplies its own Arduino/ESP shims and its own
// display object before including this file; everything below that point is the
// firmware verbatim, so the two can never drift.
#if !defined(LITH_SIM)
#define LGFX_USE_V1
#include <Arduino.h>
#include <LovyanGFX.hpp>
#include <Preferences.h>
#include <esp_ota_ops.h>
#include <qrcode.h>
#endif

// ------------------------- pin map -----------------------------------
static constexpr int PIN_TFT_SCLK = 12;
static constexpr int PIN_TFT_MOSI = 11;
static constexpr int PIN_TFT_DC   = 13;
static constexpr int PIN_TFT_CS   = 10;
static constexpr int PIN_TFT_RST  =  9;
static constexpr int PIN_TFT_BLK  =  8;

static constexpr int PIN_SW1      =  1;
static constexpr int PIN_SW2      =  2;
static constexpr int PIN_ENC_A    =  4;
static constexpr int PIN_ENC_B    =  5;
static constexpr int PIN_MOTOR    =  6;

// ------------------------- tuning ------------------------------------
static constexpr int      ENC_STEPS_PER_DETENT = 4;
static constexpr uint32_t MOTOR_PWM_FREQ = 20000;
static constexpr uint8_t  MOTOR_PWM_BITS = 8;
static constexpr int      MOTOR_LEDC_CH  = 0;
static constexpr uint8_t  HAPTIC_DUTY    = 190;
static constexpr uint8_t  HAPTIC_TAP     = 255;   // brief overdrive, crisp
static constexpr uint32_t DEBOUNCE_MS    = 25;
static constexpr uint32_t LONGPRESS_MS   = 800;

static constexpr int ROUNDS_PER_LONG = 4;
static constexpr int MIN_LEN         = 1;
static constexpr int MAX_LEN         = 90;

// ------------------------- layout ------------------------------------
static constexpr int SCR_W     = 320;
static constexpr int SCR_H     = 170;
static constexpr int MARGIN    = 18;
static constexpr int CONTENT_W = SCR_W - 2 * MARGIN;

static constexpr int LABEL_Y   = 24;
static constexpr int LABEL_SP  = 3;    // extra letter spacing
static constexpr int TIME_Y    = 86;
static constexpr int DOT_Y     = 152;
static constexpr int DOT_GAP   = 16;

// ------------------------- display driver ----------------------------
#if !defined(LITH_SIM)
class LGFX : public lgfx::LGFX_Device {
  lgfx::Panel_ST7789 _panel;
  lgfx::Bus_SPI      _bus;
  lgfx::Light_PWM    _light;

public:
  LGFX() {
    {
      auto cfg = _bus.config();
      cfg.spi_host    = SPI2_HOST;
      cfg.spi_mode    = 0;
      cfg.freq_write  = 50000000;
      cfg.freq_read   = 16000000;
      cfg.spi_3wire   = false;
      cfg.use_lock    = true;
      cfg.dma_channel = SPI_DMA_CH_AUTO;
      cfg.pin_sclk    = PIN_TFT_SCLK;
      cfg.pin_mosi    = PIN_TFT_MOSI;
      cfg.pin_miso    = -1;
      cfg.pin_dc      = PIN_TFT_DC;
      _bus.config(cfg);
      _panel.setBus(&_bus);
    }
    {
      auto cfg = _panel.config();
      cfg.pin_cs          = PIN_TFT_CS;
      cfg.pin_rst         = PIN_TFT_RST;
      cfg.pin_busy        = -1;
      cfg.panel_width     = 170;
      cfg.panel_height    = 320;
      cfg.offset_x        = 35;
      cfg.offset_y        = 0;
      cfg.offset_rotation = 2;
      cfg.readable        = false;
      cfg.invert          = true;
      cfg.rgb_order       = false;
      cfg.dlen_16bit      = false;
      cfg.bus_shared      = false;
      _panel.config(cfg);
    }
    {
      auto cfg = _light.config();
      cfg.pin_bl      = PIN_TFT_BLK;
      cfg.invert      = false;
      cfg.freq        = 44100;
      cfg.pwm_channel = 7;
      _light.config(cfg);
      _panel.setLight(&_light);
    }
    setPanel(&_panel);
  }
};

LGFX        tft;
LGFX_Sprite frame(&tft);
#endif   // !LITH_SIM  (the simulator declares tft and frame itself)

bool displayOK      = false;
bool useFrameBuffer = false;
bool bufSwapped     = false;   // probed at boot, see spriteProbe()

// ------------------------- palette -----------------------------------
#define RGB565(r, g, b) ((uint16_t)((((r) & 0xF8) << 8) | (((g) & 0xFC) << 3) | ((b) >> 3)))
static const uint16_t COL_BG       = RGB565(  9, 10, 12);
static const uint16_t COL_INK      = RGB565(238,240,245);
static const uint16_t COL_INK_DEEP = RGB565( 14, 12, 16);

struct Rgb { uint8_t r, g, b; };
static const Rgb PH_RGB[3] = {{255,138, 61}, {74,205,150}, {74,205,150}};

// ------------------------- encoder -----------------------------------
static const int8_t QUAD[16] = { 0, -1,  1,  0,
                                 1,  0,  0, -1,
                                -1,  0,  0,  1,
                                 0,  1, -1,  0 };
volatile uint8_t  encState = 0;
volatile int32_t  encRaw   = 0;
int32_t encDetentLast = 0;

void IRAM_ATTR encISR() {
  uint8_t a = digitalRead(PIN_ENC_A);
  uint8_t b = digitalRead(PIN_ENC_B);
  encState = ((encState << 2) | (a << 1) | b) & 0x0F;
  encRaw  += QUAD[encState];
}

// ------------------------- buttons -----------------------------------
static const uint8_t EV_NONE  = 0;
static const uint8_t EV_SHORT = 1;
static const uint8_t EV_LONG  = 2;
static const uint8_t EV_DOWN  = 3;   // debounced press, before the action

static const int BTN_COUNT = 2;
static const int BTN1 = 0;
static const int BTN2 = 1;

struct Button {
  int      pin;
  bool     level;
  bool     rawLast;
  uint32_t tChange;
  uint32_t tPress;
  bool     longFired;
};

Button btns[BTN_COUNT] = {
  {PIN_SW1, false, false, 0, 0, false},
  {PIN_SW2, false, false, 0, 0, false}
};

uint8_t pollButton(int idx) {
  Button &b = btns[idx];
  uint32_t now = millis();
  bool raw = (digitalRead(b.pin) == LOW);
  if (raw != b.rawLast) { b.rawLast = raw; b.tChange = now; }

  uint8_t ev = EV_NONE;
  if ((now - b.tChange) >= DEBOUNCE_MS && raw != b.level) {
    b.level = raw;
    if (b.level) {
      b.tPress    = now;
      b.longFired = false;
      ev          = EV_DOWN;
    } else if (!b.longFired) {
      ev = EV_SHORT;
    }
  }
  if (b.level && !b.longFired && (now - b.tPress) >= LONGPRESS_MS) {
    b.longFired = true;
    ev = EV_LONG;
  }
  return ev;
}

// ------------------------- motor -------------------------------------
void motorRaw(uint8_t duty) {
#if defined(ESP_ARDUINO_VERSION_MAJOR) && ESP_ARDUINO_VERSION_MAJOR >= 3
  ledcWrite(PIN_MOTOR, duty);
#else
  ledcWrite(MOTOR_LEDC_CH, duty);
#endif
}

void motorInit() {
#if defined(ESP_ARDUINO_VERSION_MAJOR) && ESP_ARDUINO_VERSION_MAJOR >= 3
  ledcAttach(PIN_MOTOR, MOTOR_PWM_FREQ, MOTOR_PWM_BITS);
#else
  ledcSetup(MOTOR_LEDC_CH, MOTOR_PWM_FREQ, MOTOR_PWM_BITS);
  ledcAttachPin(PIN_MOTOR, MOTOR_LEDC_CH);
#endif
  motorRaw(0);
}

// ------------------------- haptics -----------------------------------
// on/off durations in ms, alternating, zero terminates.
// A tap is short and driven hard: the eccentric mass needs a sharp kick to
// register at all, and a gentle 14 ms nudge is simply not felt.
static const uint16_t PAT_TAP[]    = {14, 0};
static const uint16_t PAT_START[]  = {45, 60, 45, 0};
static const uint16_t PAT_BREAK[]  = {200, 130, 200, 0};
static const uint16_t PAT_LONG[]   = {200, 130, 200, 130, 320, 0};
static const uint16_t PAT_BACK[]   = {320, 0};

const uint16_t *hapSeq  = nullptr;
uint8_t  hapIdx  = 0;
uint8_t  hapDuty = HAPTIC_DUTY;
uint32_t hapNext = 0;

// Shared between loop() and the timer task below, so the state transition
// happens under a lock; the peripheral write is kept outside it.
static portMUX_TYPE hapMux = portMUX_INITIALIZER_UNLOCKED;

void hapticPlay(const uint16_t *seq, uint8_t duty) {
  portENTER_CRITICAL(&hapMux);
  hapSeq  = seq;
  hapIdx  = 0;
  hapDuty = duty;
  hapNext = millis();
  portEXIT_CRITICAL(&hapMux);
}

void hapticService() {
  uint8_t out    = 0;
  bool    change = false;

  portENTER_CRITICAL(&hapMux);
  if (hapSeq != nullptr) {
    uint32_t now = millis();
    if ((int32_t)(now - hapNext) >= 0) {
      uint16_t d = hapSeq[hapIdx];
      if (d == 0) {
        hapSeq = nullptr;
        out    = 0;
      } else {
        out     = ((hapIdx % 2) == 0) ? hapDuty : 0;
        hapNext = now + d;
        hapIdx++;
      }
      change = true;
    }
  }
  portEXIT_CRITICAL(&hapMux);

  if (change) motorRaw(out);
}

// The render blocks loop() for ~28 ms, which would quantise a 14 ms tap to
// roughly twice its length and turn the multi-pulse patterns to mush. Run
// the queue off a 2 ms timer so pulse lengths mean what they say.
static esp_timer_handle_t hapTimer = nullptr;

void hapticTimerCb(void *) { hapticService(); }

void hapticTimerInit() {
  esp_timer_create_args_t args = {};
  args.callback              = &hapticTimerCb;
  args.arg                   = nullptr;
  args.dispatch_method       = ESP_TIMER_TASK;
  args.name                  = "haptic";
  args.skip_unhandled_events = true;
  if (esp_timer_create(&args, &hapTimer) == ESP_OK)
    esp_timer_start_periodic(hapTimer, 2000);
  else
    Serial.println(F("haptic timer failed - falling back to loop timing"));
}

// ------------------------- timer state -------------------------------
static const uint8_t PH_FOCUS = 0;
static const uint8_t PH_SHORT = 1;
static const uint8_t PH_LONG  = 2;

int lenMin[3] = {25, 5, 15};
const char *phaseName[3] = {"FOCUS", "BREAK", "LONG BREAK"};

uint8_t  phase         = PH_FOCUS;
bool     running       = false;
uint32_t phaseRemainMs = 0;
uint32_t lastTickMs    = 0;
int      focusDone     = 0;
uint8_t  editField     = PH_FOCUS;

uint32_t phaseLenMs() { return (uint32_t)lenMin[phase] * 60000UL; }

void loadPhase() {
  phaseRemainMs = phaseLenMs();
  lastTickMs    = millis();
}

void advance(bool byUser) {
  if (phase == PH_FOCUS) {
    if (!byUser) focusDone++;
    bool longBreak = (focusDone > 0) && (focusDone % ROUNDS_PER_LONG == 0);
    phase   = longBreak ? PH_LONG : PH_SHORT;
    running = true;
    hapticPlay(longBreak ? PAT_LONG : PAT_BREAK, HAPTIC_DUTY);
  } else {
    phase   = PH_FOCUS;
    running = false;
    hapticPlay(PAT_BACK, HAPTIC_DUTY);
  }
  loadPhase();
}

void toggleRun() {
  running = !running;
  lastTickMs = millis();
  hapticPlay(running ? PAT_START : PAT_TAP, running ? HAPTIC_DUTY : HAPTIC_TAP);
}

void resetPhase() {
  running = false;
  loadPhase();
  hapticPlay(PAT_TAP, HAPTIC_TAP);
}

void timerService() {
  if (!running) { lastTickMs = millis(); return; }
  uint32_t now = millis();
  uint32_t dt  = now - lastTickMs;
  lastTickMs = now;

  if (dt >= phaseRemainMs) {
    phaseRemainMs = 0;
    advance(false);
  } else {
    phaseRemainMs -= dt;
  }
}

// ------------------------- render ------------------------------------
int spacedWidth(LovyanGFX *g, const char *s, int extra) {
  int n = strlen(s);
  return g->textWidth(s) + (n > 1 ? extra * (n - 1) : 0);
}

void drawSpaced(LovyanGFX *g, const char *s, int cx, int y, int extra) {
  int x = cx - spacedWidth(g, s, extra) / 2;
  char c[2] = {0, 0};
  g->setTextDatum(textdatum_t::top_left);
  for (int i = 0; s[i]; i++) {
    c[0] = s[i];
    g->drawString(c, x, y);
    x += g->textWidth(c) + extra;
  }
}

// ------------------------- fluid -------------------------------------
// Metaball field sampled on a coarse grid, then bilinearly upsampled to
// pixels. The liquid surface is itself a field source, so blobs drifting
// near it stretch and merge into the body rather than sitting on top of
// it as hard circles. Level is time remaining, so the vessel drains.
static constexpr int CELL  = 5;
static constexpr int FW    = SCR_W / CELL + 2;
static constexpr int FH    = SCR_H / CELL + 2;
static constexpr int NBLOB = 5;

static constexpr float FIELD_T = 1.00f;   // at or above this is inside
static constexpr float RIM_T   = 1.70f;   // brighter band just inside
static constexpr float SURF_K  = 44.0f;   // reach of the surface, px^2

// Depth shading across the body. RGB565 carries 5 bits of red and blue but
// 6 of green, so an amber ramp steps twice as coarsely as a teal one and
// bands about twice as hard. A 4x4 ordered dither breaks the contours into
// a stipple the panel is too dense to resolve, which costs one AND in the
// inner loop and buys back the gradient. Set to 0 for a flat block colour.
static constexpr float DEPTH_FADE = 0.22f;

static const uint8_t BAYER4[4][4] = {
  { 0,  8,  2, 10},
  {12,  4, 14,  6},
  { 3, 11,  1,  9},
  {15,  7, 13,  5},
};

// LovyanGFX keeps 16bpp sprite pixels in SPI wire order, which is byte
// swapped relative to the RGB565 literals above. Writing the buffer raw
// bypasses its colour conversion, so every constant we poke in or compare
// against has to be put through here first.
static inline uint16_t store(uint16_t c) {
  return bufSwapped ? (uint16_t)((c >> 8) | (c << 8)) : c;
}

struct Blob { float cx, rel, ax, ay, fx, fy, ph, r; };

// lissajous drift: cheaper than a physics step and never quite repeats
static Blob blobs[NBLOB] = {
  { 66, -18, 44, 22, 0.23f, 0.31f, 0.0f, 30},
  {158,  14, 60, 30, 0.17f, 0.26f, 1.7f, 26},
  {252,  -6, 42, 26, 0.29f, 0.19f, 3.1f, 28},
  {112,  40, 52, 20, 0.13f, 0.37f, 4.4f, 22},
  {214,  30, 48, 24, 0.21f, 0.23f, 5.6f, 24},
};

static float    fld[FH][FW];
static float    surf[FW];
static float    bX[NBLOB], bY[NBLOB], bR2[NBLOB];
static int      fldBlobs = NBLOB;     // blobs live in the current field
static uint16_t bodyDith[SCR_H][4];   // depth ramp, one entry per x phase

// nblob 0 gives a bare wave with nothing breaking out of it, which is what
// the splash wants; the timer passes NBLOB for the full lamp.
void fluidStep(float t, float level, bool ambient, int nblob) {
  float base = SCR_H * (1.0f - level);
  for (int i = 0; i < FW; i++) {
    float x = i * CELL;
    surf[i] = base + 5.0f * sinf(x * 0.028f + t * 1.10f)
                   + 3.0f * sinf(x * 0.017f - t * 0.73f);
  }

  // idle lets the blobs roam mid-screen; running tethers them to the
  // surface so the whole mass settles as the level drops
  float anchor = ambient ? SCR_H * 0.52f : base;
  for (int i = 0; i < nblob; i++) {
    Blob &b = blobs[i];
    bX[i]  = b.cx + b.ax * sinf(t * b.fx + b.ph);
    bY[i]  = anchor + b.rel + b.ay * sinf(t * b.fy + b.ph * 1.3f);
    bR2[i] = b.r * b.r;
  }
  fldBlobs = nblob;

  for (int gy = 0; gy < FH; gy++) {
    float py = gy * CELL;
    for (int gx = 0; gx < FW; gx++) {
      float d = py - surf[gx];
      if (d >= 0.0f) { fld[gy][gx] = 99.0f; continue; }   // below the line
      float px = gx * CELL;
      float f  = SURF_K / (d * d);
      for (int i = 0; i < fldBlobs; i++) {
        float dx = px - bX[i], dy = py - bY[i];
        float d2 = dx * dx + dy * dy;
        if (d2 < 1.0f) d2 = 1.0f;
        f += bR2[i] / d2;
      }
      fld[gy][gx] = f;
    }
  }
}

// Chrome is already in the buffer as COL_INK. Where liquid covers it we
// swap to COL_INK_DEEP, so the readout flips light-on-dark to dark-on-lit
// and stays legible at any level. The bitmap fonts are not antialiased,
// so an exact colour compare is a sound test for "this pixel is text".
void fluidRaster(uint16_t *fb, const Rgb &c, float fade) {
  int rr = c.r + 60, gg = c.g + 60, bb = c.b + 55;
  if (rr > 255) rr = 255;
  if (gg > 255) gg = 255;
  if (bb > 255) bb = 255;
  const uint16_t rim    = store(RGB565(rr, gg, bb));
  const uint16_t inkOn  = store(COL_INK);
  const uint16_t inkOff = store(COL_INK_DEEP);

  // Nudge each channel by up to one quantisation step before it truncates:
  // red and blue span 8 codes per step, green 4.
  for (int y = 0; y < SCR_H; y++) {
    float k  = 1.0f - fade * ((float)y / SCR_H);
    float rf = c.r * k, gf = c.g * k, bf = c.b * k;
    const uint8_t *brow = BAYER4[y & 3];
    for (int p = 0; p < 4; p++) {
      int d  = brow[p];
      int rq = (int)(rf + d * 0.50f);
      int gq = (int)(gf + d * 0.25f);
      int bq = (int)(bf + d * 0.50f);
      if (rq > 255) rq = 255;
      if (gq > 255) gq = 255;
      if (bq > 255) bq = 255;
      bodyDith[y][p] = store(RGB565(rq, gq, bq));
    }
  }

  // Most blocks are wholly inside or wholly outside; only the contour needs
  // interpolating. Testing the four corners first skips the float work for
  // the bulk of the screen, which is what keeps this inside a frame budget.
  const float INV_CELL = 1.0f / CELL;

  for (int gy = 0; gy < FH - 1; gy++) {
    int y0 = gy * CELL;
    if (y0 >= SCR_H) break;
    int rows = (y0 + CELL > SCR_H) ? SCR_H - y0 : CELL;

    for (int gx = 0; gx < FW - 1; gx++) {
      int x0 = gx * CELL;
      if (x0 >= SCR_W) break;
      int n = (x0 + CELL > SCR_W) ? SCR_W - x0 : CELL;

      float f00 = fld[gy][gx],     f10 = fld[gy][gx + 1];
      float f01 = fld[gy + 1][gx], f11 = fld[gy + 1][gx + 1];

      float lo = f00, hi = f00;
      if (f10 < lo) lo = f10;  if (f10 > hi) hi = f10;
      if (f01 < lo) lo = f01;  if (f01 > hi) hi = f01;
      if (f11 < lo) lo = f11;  if (f11 > hi) hi = f11;

      if (hi < FIELD_T) continue;                 // wholly background

      if (lo >= RIM_T) {                          // wholly body
        for (int sy = 0; sy < rows; sy++) {
          uint16_t       *row = &fb[(y0 + sy) * SCR_W + x0];
          const uint16_t *bod = bodyDith[y0 + sy];
          for (int sx = 0; sx < n; sx++)
            row[sx] = (row[sx] == inkOn) ? inkOff : bod[(x0 + sx) & 3];
        }
        continue;
      }

      for (int sy = 0; sy < rows; sy++) {         // contour block
        int   y  = y0 + sy;
        float ty = sy * INV_CELL;
        float a  = f00 + (f01 - f00) * ty;
        float b  = f10 + (f11 - f10) * ty;
        float st = (b - a) * INV_CELL;
        float v  = a;
        uint16_t       *row = &fb[y * SCR_W + x0];
        const uint16_t *bod = bodyDith[y];
        for (int sx = 0; sx < n; sx++) {
          if (v >= FIELD_T) {
            row[sx] = (row[sx] == inkOn) ? inkOff
                    : (v < RIM_T ? rim : bod[(x0 + sx) & 3]);
          }
          v += st;
        }
      }
    }
  }
}

// Idle shows the setting the encoder is editing, so turning the knob moves
// the big number directly. Running shows the countdown. One number, always
// the thing you are acting on.
void drawChrome(LovyanGFX *g, uint8_t shown, uint32_t secs) {
  char buf[16];

  g->setFont(&fonts::Font2);
  g->setTextColor(COL_INK, COL_BG);
  drawSpaced(g, phaseName[shown], SCR_W / 2, LABEL_Y, LABEL_SP);

  snprintf(buf, sizeof(buf), "%02lu:%02lu",
           (unsigned long)(secs / 60), (unsigned long)(secs % 60));
  g->setFont(&fonts::Font8);
  g->setTextColor(COL_INK, COL_BG);
  g->setTextDatum(textdatum_t::middle_center);
  g->drawString(buf, SCR_W / 2, TIME_Y);

  int ring = focusDone % ROUNDS_PER_LONG;
  if (focusDone > 0 && ring == 0) ring = ROUNDS_PER_LONG;
  int x0 = SCR_W / 2 - ((ROUNDS_PER_LONG - 1) * DOT_GAP) / 2;
  for (int i = 0; i < ROUNDS_PER_LONG; i++) {
    int cx = x0 + i * DOT_GAP;
    if (i < ring) g->fillCircle(cx, DOT_Y, 3, COL_INK);
    else          g->drawCircle(cx, DOT_Y, 3, COL_INK);
  }
}

void render() {
  bool     fresh = !running && phaseRemainMs == phaseLenMs();
  uint8_t  shown = fresh ? editField : phase;
  float    t     = millis() * 0.001f;
  uint32_t total = phaseLenMs();

  uint32_t secs  = fresh ? (uint32_t)lenMin[editField] * 60
                         : (phaseRemainMs + 999) / 1000;
  float    level = fresh ? 0.17f + 0.05f * sinf(t * 0.6f)
                         : (total ? (float)phaseRemainMs / (float)total : 0.0f);

  if (!useFrameBuffer) {
    tft.fillScreen(COL_BG);
    drawChrome(&tft, shown, secs);
    return;
  }

  frame.fillScreen(COL_BG);
  drawChrome(&frame, shown, secs);
  fluidStep(t, level, fresh, NBLOB);
  fluidRaster((uint16_t *)frame.getBuffer(), PH_RGB[shown], DEPTH_FADE);
  frame.pushSprite(0, 0);
}
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
void loop() {
  handleSerial();

  // tap on the press edge so the button answers under your finger; the
  // action's own pattern follows on release or at the long-press mark
  uint8_t e1 = pollButton(BTN1);
  if (e1 == EV_DOWN)  hapticPlay(PAT_TAP, HAPTIC_TAP);
  if (e1 == EV_SHORT) toggleRun();
  if (e1 == EV_LONG)  resetPhase();

  uint8_t e2 = pollButton(BTN2);
  if (e2 == EV_DOWN)  hapticPlay(PAT_TAP, HAPTIC_TAP);
  if (e2 == EV_SHORT) advance(true);
  if (e2 == EV_LONG)  nextField();

  noInterrupts();
  int32_t raw = encRaw;
  interrupts();
  int32_t det = raw / ENC_STEPS_PER_DETENT;
  if (det != encDetentLast) {
    int delta = (int)(det - encDetentLast);
    encDetentLast = det;
    if (!running) adjustField(delta);
  }

  timerService();
  hapticService();

  static uint32_t tBeat = 0;
  if (millis() - tBeat >= 5000) {
    tBeat = millis();
    Serial.printf("up %lus  heap %u (min %u)  stack free %u\n",
                  (unsigned long)(millis() / 1000),
                  (unsigned)ESP.getFreeHeap(), (unsigned)ESP.getMinFreeHeap(),
                  (unsigned)uxTaskGetStackHighWaterMark(NULL));
  }

  static uint32_t tNext = 0;
  uint32_t now = millis();
  if (displayOK && now >= tNext) {
    tNext = now + 40;
    uint32_t t0 = micros();
    render();
    if (reportFrame) {
      reportFrame = false;
      Serial.printf("frame %lu us\n", (unsigned long)(micros() - t0));
    }
  }
}

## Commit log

2026-07-26 first bring-up, everything talks
    PlatformIO firmware for bring-up testing the Lith hardware: ST7789V2
    170x320 display via LovyanGFX, rotary encoder, two switches, and a
    vibration motor driven through an NPN low-side switch.
    [main.cpp]
2026-07-26 Lith hardware bring-up: ESP32-S3-Zero display, encoder, switches, motor
    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
    [main.cpp]
2026-07-28 pomodoro timer with the metaball fluid
    Layout:
    - bring-up test moves to sketches/bringup.cpp, built via `pio run -e bringup`
    - pomodoro becomes src/main.cpp and the default env
    - [common] section in platformio.ini shared by both
    UI:
    - liquid level is time remaining, so the vessel drains over a session
    - surface is itself a metaball field source, so drifting blobs stretch
    and merge into it instead of sitting on top as hard circles
    - idle doubles as an ambient screensaver over a shallow breathing pool
    - chrome is drawn first in COL_INK and the raster swaps it to COL_INK_DEEP
    where liquid covers, so the readout inverts and stays legible
    - encoder edits the big number directly, which remove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
    [bringup.cpp, main.cpp]
2026-07-28 Pomodoro timer with metaball fluid UI
    - encoder edits the big number directly, which removed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
    [bringup.cpp, main.cpp]
2026-08-08 added QR codes and got the haptics buzzing
    [main.cpp]
2026-08-09 motor fixes, tidier splash hint
    [bringup.cpp, main.cpp]
2026-08-09 Enhance motor control and diagnostics; update splash screen hint formatting
2026-08-10 benchmarked the providers for latency and cost
    [lith_provider_latency.xlsx]
2026-08-12 added the webp frames the site serves
2026-08-16 ran the ui judge study
    [gate1_compile.csv, gate1_repair.csv, gate2_render_deployed.csv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]
2026-08-21 hero: the timer running on a lith
2026-08-21 edited note
    Removed note explaining the timer's rendering process.
2026-08-21 added the cad and pcb source and a video folder
    [CONN-SMD_8P-P1.00_XUNPU_WAFER-100L-8P.step, CONN-TH_3P-P2.00_HX-2.0MM-3P-ZZ-MS.step, enclosure_bottom.stl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]
2026-08-22 put the scroll wheel label back
2026-08-24 Add USB CDC/HID heuristic to Oldowan's device profile
    A generated macropad sketch went HID-only and dropped CDC, silently
    taking the serial/flashing port away from the owner. Codify the
    composite CDC+HID requirement and the manual BOOT+RESET recovery path
    so future sketches don't repeat it.
2026-08-27 added a render of the v1.0 board
